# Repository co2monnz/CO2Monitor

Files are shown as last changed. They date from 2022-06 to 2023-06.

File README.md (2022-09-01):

# CO2 and Air Quality Monitor

**ESP32 DevKit (30pin) or Feather based**

Inspired by and many thanks to
[make-IoT / CO2-Ampel](https://github.com/make-IoT/CO2-Ampel) and [Umwelt-Campus](https://www.umwelt-campus.de/en/forschung/projekte/iot-werkstatt/translate-to-englisch-ideen-zur-corona-krise)

# Why use a CO2 Monitor?

A large risk of Covid-19 transmission stems from airborne virus particles that can linger in poorly ventilated spaces for hours. This has been recognised by the WHO. To lower the risk of infection, particularly in busier indoor settings, good ventilation and regular air exchange are key.

This is where measuring CO2 levels in rooms can provide a direct and good indication of sufficient ventilation which correlates with reduced viral load and low risk of virus transmission. Good air quality is also important for creating a good learning or work environment.

Poorly ventilated rooms often feel stale and ‘stuffy’, but by the time we can feel that the air quality is already pretty poor; early indications are easily missed. A sensitive and consistent CO2 monitor can accurately measure CO2 levels and display an easy-to-understand and actionable traffic light indication with orange as an indication of worsening air quality and red as a reminder to open a window.

The data collected by the sensors should be logged and made available for further consumption. It can be visualised on a central school/organisation-wide dashboard and used to establish a baseline and understand patterns or identify rooms that are more difficult to ventilate, as well as providing potential alerting or to remotely checking a room before another group uses it.

These CO2 monitors have been tested in collaboration with researchers from the public health department of the University of Otago.

## Resources

- [RNZ interview](https://www.rnz.co.nz/national/programmes/afternoons/audio/2018840570/handyman-dad-builds-units-to-monitor-class-air-quality)
- [The What, How and Why of CO2 Monitoring](https://makezine.com/2021/05/17/the-what-how-and-why-of-co-monitoring/)
- [Ventilation in NZ schools during the Omicron wave – results from a preliminary study](https://blogs.otago.ac.nz/pubhealthexpert/ventilation-in-nz-schools-during-the-omicron-wave-results-from-a-preliminary-study/)
- [Ministry of Education Indoor Air Quality and Thermal Comfort](https://assets.education.govt.nz/public/Documents/Primary-Secondary/Property/Design/Indoor-Air-Quality-and-Thermal-Comfort-V2-v2.0-2022.pdf)
- [What size particle is important to transmission of COVID-19?](https://www.aerosol.mech.ubc.ca/what-size-particle-is-important-to-transmission/)
- [Comparison of Low-Cost Particulate Matter Sensors for Indoor Air Monitoring during COVID-19 Lockdown](https://www.ncbi.nlm.nih.gov/pmc/articles/PMC7766947/pdf/sensors-20-07290.pdf)

# Sections

- [PCBs](#pcbs) listing the different PCB designs, [parts list](pcb/CO2%20Monitor%20V0.5%20through-hole/bom.md) and [assembly guide](pcb/CO2%20Monitor%20V0.5%20through-hole/step-by-step.md)
- [Firmware](#firmware) describing the device's software features and how to use them
- [Sensors](#sensors) has more information on the available sensors
- [Calibration](#calibration) has some important information on keeping the readings accurate
- [Hardware](#hardware) has a little more background on the controller and wiring

# PCBs

There are now 2 new PCB designs, one for SMD components and another one solely using easy to solder through-hole components.

## Through hole version

[BOM](pcb/CO2%20Monitor%20V0.5%20through-hole/bom.md)

[Assembly guide](pcb/CO2%20Monitor%20V0.5%20through-hole/step-by-step.md)

- uses only through hole components and can be hand soldered
- ESP 32 Devkit (30 pin)
- SCD30 NDIR CO2 sensor
- optional 128x64 0.96 inch OLED display
- 3 x 5mm red/yellow/green LEDs
- optional I2C JST-PH connector for additional connectivity (e.g. SPS30 particulate matter sensor)
- optional USB-B connector to power the monitor

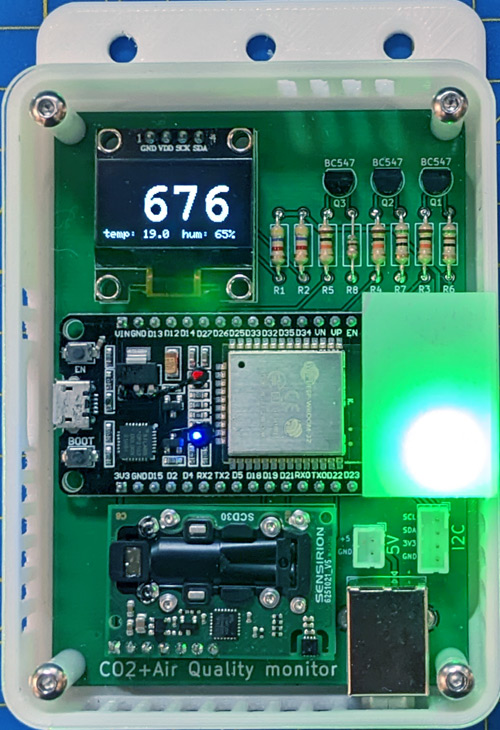
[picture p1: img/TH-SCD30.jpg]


## SMD version

- ESP 32 Devkit (30 pin)
- SCD40 or SCD30 NDIR CO2 sensor
- optional BME680 IAQ/VOC sensor
- optional 128x64 0.96 inch OLED display
- alternatively Feather wing footprint for easy expansion modules
- combined footprints for either 3 Neopixels (WS2812B 5050) or 3 x 5mm red/yellow/green LEDs
- I2C JST-PH connector for additional connectivity (e.g. SPS30 particulate matter sensor)
- optional USB-B connector to power the monitor

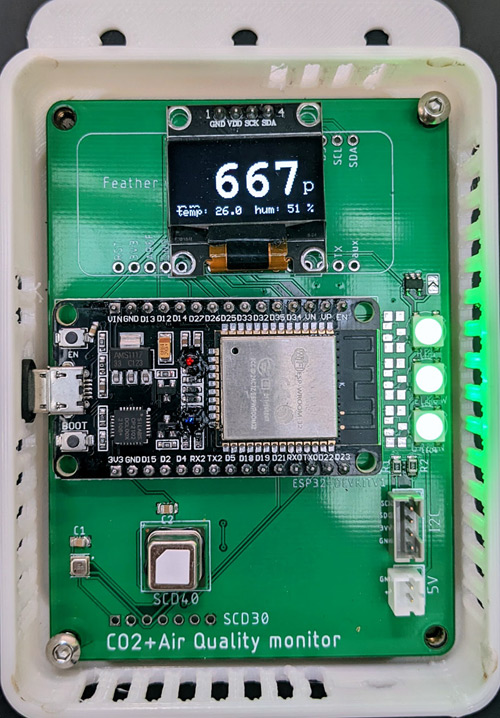
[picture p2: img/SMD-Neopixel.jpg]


## First generation

- ESP 32 Devkit (30 pin)
- SCD40 or SCD30 NDIR CO2 sensor
- optional BME680 IAQ/VOC sensor
- Feather wing footprint for easy expansion modules
- 3 x 5mm red/yellow/green LEDs
- I2C JST-PH connector for additional connectivity (e.g. SPS30 particulate matter sensor)
- RFM96 LoRa modem and u.Fl/SMA footprint

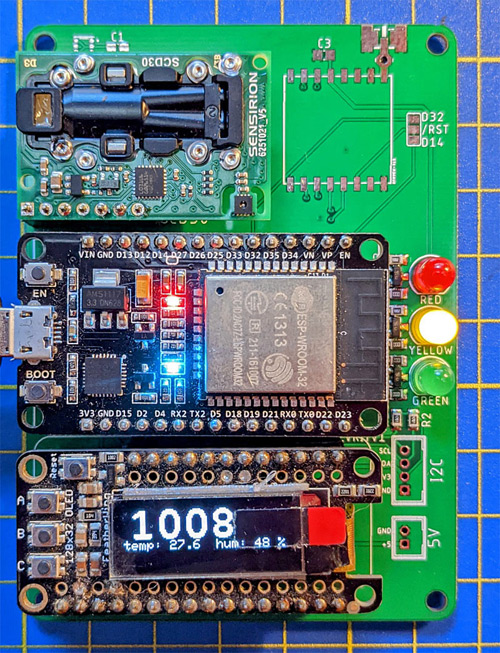
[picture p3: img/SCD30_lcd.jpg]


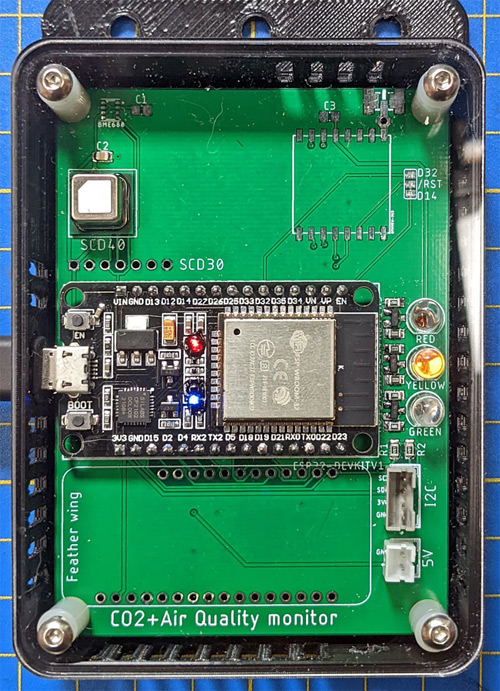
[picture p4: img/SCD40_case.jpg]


## First generation with Neopixel feather wing

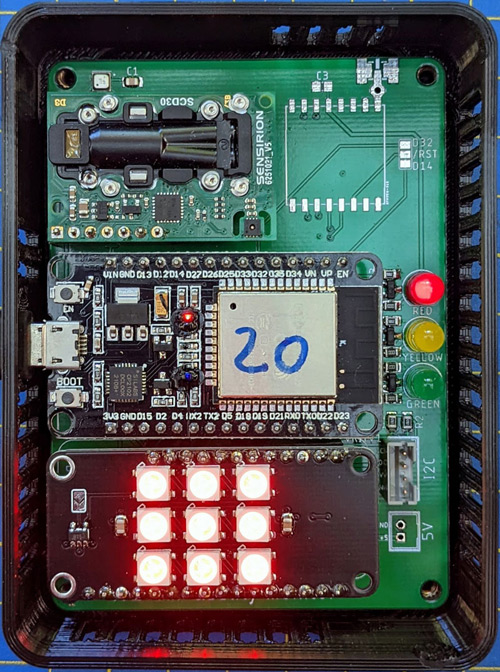
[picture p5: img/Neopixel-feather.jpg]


# Firmware




## Wifi

Supports [ESPAsync WiFiManager](https://github.com/khoih-prog/ESPAsync_WiFiManager) to set up wireless credentials and further configuration.

### Up to v1.2.3

If no wifi credentials have been configured yet it will automatically launch an AP using the SSID `CO2-Monitor-<ESP32mac>`.

Once wifi credentials have been configured briefly pressing the `Boot` button on the ESP32 puts the device in configuration mode:

### From v1.2.4

Pressing the `Boot` button for less than 2 seconds launches an AP using the SSID `CO2-Monitor-<ESP32mac>`. Connecting to this AP allows the Wifi credentials for the monitor to be set.

A password for the AP can be configured in the file `extra.ini` which needs to be created by copying [extra.template.ini](extra.template.ini) and applying the desired changes.



## Configuration

The monitor is configured via the `config.json` file on the ESP32 file system. There are 3 ways the configuration can be changed:

- via the web interface
- by directly editing [config.json](data/config.json) and uploading it via `Upload Filesystem Image`
- via MQTT (once connected)

## Backend using Mosquitto - Node-Red - InfluxDB - Grafana

[Docker compose file](./docker/docker.md) to set up the database and dashboards.

## MQTT

Sensor readings can be published via MQTT for centralised storage and visualition. Each node is configured with its own id and will then publish under `co2monitor/<id>/up/sensors`. The top level topic `co2monitor` is configurable. Downlink messages to nodes can be sent to each individual node using the id in the topic `co2monitor/<id>/down/<command>`, or to all nodes when omitting the id part `co2monitor/down/<command>`

SCD3x/SCD4x

```
{
  "co2": 752,
  "temperature": "21.6",
  "humidity": "52.1"
}
```

BME680

```
{
  "iaq": 19,
  "temperature": "19.2",
  "humidity": "75.6",
  "pressure": 1014
}
```

SPS30

```
{
  "pm0.5": 16,
  "pm1": 19,
  "pm2.5": 19,
  "pm4": 19,
  "pm10": 19
}
```

Sending `co2monitor/<id>/down/getConfig` will triger the node to reply with its current settings under `co2monitor/<id>/up/config`

```
{
  "appVersion": 1,
  "altitude": 10,
  "co2YellowThreshold": 700,
  "co2RedThreshold": 900,
  "co2DarkRedThreshold": 1200,
  "iaqYellowThreshold": 100,
  "iaqRedThreshold": 200,
  "iaqDarkRedThreshold": 300,
  "brightness": 255,
  "mac": "xxyyzz",
  "ip": "1.2.3.4",
  "scd40": true,
  "scd30": true,
  "bme680": true,
  "lcd": true,
  "sps30": true,
  "sps30AutoCleanInt": 604800,
  "sps30Status": 0,
  "tempOffset": "7.0",
  "ssd1306Rows": 64,
  "greenLed": 27,
  "yellowLed": 26,
  "redLed": 25,
  "neopixelData": 16,
  "neopixelNumber": 3,
  "featherMatrixData": 27,
  "featherMatrixClock": 13,
  "hub75R1": 15,
  "hub75G1": 2,
  "hub75B1": 4,
  "hub75R2": 16,
  "hub75G2": 12,
  "hub75B2": 17,
  "hub75ChA": 5,
  "hub75ChB": 18,
  "hub75ChC": 19,
  "hub75ChD": 14,
  "hub75Clk": 27,
  "hub75Lat": 26,
  "hub75Oe": 25
}
```

A message to `co2monitor/<id>/down/setConfig` will set the node's configuration to the provided parameters. Note that changes to the hardware configuration will trigger a reboot.

```
{
  "altitude": 10,
  "co2YellowThreshold": 700,
  "co2RedThreshold": 900,
  "co2DarkRedThreshold": 1200,
  "iaqYellowThreshold": 100,
  "iaqRedThreshold": 200,
  "iaqDarkRedThreshold": 300,
  "brightness": 255,
  "ssd1306Rows": 64,
  "greenLed": 27,
  "yellowLed": 26,
  "redLed": 25,
  "neopixelData": 16,
  "neopixelNumber": 3,
  "featherMatrixData": 27,
  "featherMatrixClock": 13,
  "hub75R1": 15,
  "hub75G1": 2,
  "hub75B1": 4,
  "hub75R2": 16,
  "hub75G2": 12,
  "hub75B2": 17,
  "hub75ChA": 5,
  "hub75ChB": 18,
  "hub75ChC": 19,
  "hub75ChD": 14,
  "hub75Clk": 27,
  "hub75Lat": 26,
  "hub75Oe": 25
}
```

A message to `co2monitor/<id>/down/setTemperatureOffset` will set the SCD3x/SCD4x's temperature offset (float, °C):

```
7.0
```

A message to `co2monitor/<id>/down/calibrate` will manually calibrate the SCD3x/SCD4x sensor to the given value:

```
412
```

A message to `co2monitor/<id>/down/setSPS30AutoCleanInterval` will set the SPS30 fan auto-clean interval in seconds to the given value:

```
604800
```

A message to `co2monitor/<id>/down/cleanSPS30` will run a fan clean on the SPS30.

A message to `co2monitor/<id>/down/reboot` will trigger a reset on the node.

### MQTT TLS support

To connect to an MQTT server using TLS (recommended) you need to enable TLS in the configuration by setting `mqttUseTls` to `true`. You also need to supply a root CA certificate in PEM format on the file system as `/mqtt_root_ca.pem` and/or a client certificate and key for using mTLS as `mqtt_client_cert.pem` and `mqtt_client_key.pem`. These files can be uploaded using the `Upload Filesystem Image` project task in PlatformIO. Alternatively you can set `mqttInsecure` to `true` to disable certificate validation altogether.

## Supported sensors

- [SCD3x NDIR CO2, temperature and humidity sensor](https://www.sensirion.com/en/environmental-sensors/carbon-dioxide-sensors/carbon-dioxide-sensors-scd30/)
- [SCD4x NDIR CO2, temperature and humidity sensor](https://www.sensirion.com/en/environmental-sensors/carbon-dioxide-sensors/carbon-dioxide-sensor-scd4x/)
- [BME680 IAQ, VOC, temperature and humidity sensor](https://www.bosch-sensortec.com/products/environmental-sensors/gas-sensors/bme680/)
- [SPS30 Small Particulate matter sensor](https://sensirion.com/products/catalog/SPS30/)

## Supported displays

- [128x32 OLED feather wing](https://www.adafruit.com/product/2900)
- [SSD1306 based displays](https://www.aliexpress.com/wholesale?SearchText=128X64+SSD1306)
- [Dot Star feather wing](https://www.adafruit.com/product/3449)
- [Neopixel feather wing](https://www.adafruit.com/product/2945)
- Neopixel strips
- [HUB75 based RBG Matrix panels](https://www.adafruit.com/?q=RGB+LED+Matrix+Panel&sort=BestMatch)

# Sensors

The presence of supported I2C based sensors/displays will be automatically detected on start-up.

## SCD3x

A SCD3x NDIR CO2 sensor can be connected to the designated footprint and will provide CO2, temperature and humidity readings via I2C. It supports a separate ready signal which is connected to the ESP32.

## SCD4x

A SCD4x NDIR CO2 sensor can be soldered directly onto the pcb and provides CO2, temperature and humidity readings via I2C.

## BME680

A BME680 sensor can be directly soldered onto the dedicates footprint or connected via the I2C JST header [Adafruit BME680](https://www.adafruit.com/product/3660), [STEMMA to JST SH Cable](https://www.adafruit.com/product/4424) to provide additional VOC and AIQ measurements.

## SPS30 Particulate matter sensor

The SPS30 sensor can be connected to the I2C and 5V JST connectors of the pcb.

| fn  | I2C | 5V  | SPS30 |
| --- | --- | --- | ----- |
| VDD | | +5V | 1 |
| SDA | SDA | | 2 |
| SCL | SCL | | 3 |
| SEL | GND | | 4 |
| GND | | GND | 5 |

## other

Other I2C based sensors can be wired using the JST-PH I2C header.

# Calibration

CO2 sensors need to be regularly calibrated to provide reliable measurements. The used sensors support auto-calibration and that is enabled in the firmware. It works by looking over measurements over a period and calibrating the lowest value against 420ppm (configurable in the firmware). This is based on the assumption that the monitor 'sees' clean outside air about once a week. If that cannot be achieved the firmware also allows for a forced calibration against a given value. Please also make sure to set the altitude setting according to the monitor location. For details please check the sensor's datasheets.

## From v1.2.4

Manual calibration can be triggered by pressing the `Boot` button for more than 5 seconds. Make sure the monitor has been exposed to fresh outside air for a while and be careful not to breathe towards the monitor when doing this.

# Hardware

The board was designed to use an ESP32 or a Feather controller

## ESP32

When an ESP32 is used the feather footprint can be used to drive feather wings. Since some pins are shared with other components please check carefully before connecting a feather.

## Feather

A feather controller can be used to drive the sensors and LEDs, but unfortunately not the RFM96.

## Pin mapping

| ESP32 Devkit (30 pin) | fn | Feather pin | fn | LEDs | SCD3x/4x/BME680/SPS30 | Neopixel |
| --- | --- | --- | ----- | --- | --- | --- |
| 1 | EN | | | | | |
| 2 | VP-D36 | 9 | A4 | | | |
| 3 | VN-D39 | 8 | A3 | | | |
| 4 | D34 | 7 | A2 | | | |
| 5 | D35 | | | | RDY (SCD3x) | |
| 6 | D32 | 20 | D6 | | | |
| 7 | D33 | 22 | D10 | | | |
| 8 | D25 | 6 | A1 | Red | | |
| 9 | D26 | 5 | A0 | Yellow | | |
| 10 | D27 | 23 | D11 | Green  | | |
| 11 | D14 | 19 | D5 | | | |
| 12 | D12 | 24 | D12 | | | |
| 13 | D13 | 25 | D13 | | | |
| 14 | GND | | | | | |
| 15 | V_in | 26 | V_USB | | | |
| 16 | 3V3 | 2 | 3V3 | | | |
| 17 | GND | 4 | GND | | | |
| 18 | D15 | 21 | D9 | | | |
| 19 | D2 | | | | | |
| 20 | D4 | 10 | A5 | | | |
| 21 | D16 | | | | | DIN |
| 22 | D17 | | | | | |
| 23 | D5/CS0 | | | | | |
| 24 | D18/SCK  | 11 | SCK | | | |
| 25 | D19/MISO | 13 | MISO  | | | |
| 26 | D21/SDA  | 17 | SDA | | SDA | |
| 27 | D3/Rx | 14 | Rx | | | |
| 28 | D1/TxD | 15 | Tx | | | |
| 29 | D22/SCL  | 18 | SCL | | SCL | |
| 30 | D23/MOSI | 12 | MOSI  | | | |
| | | 1 | RST | | |
| | | 3 | AREF  | | |
| | | 16 | aux | | |
| | | 27 | En | | |
| | | 28 | VBat  | | |

## LEDs

The board has room for 3 x 5mm LEDs for traffic light style indication. Each is driven by a transistor to relieve the ESP32/Feather GPIO pins. High intensity LEDs allow for good visibility, but can also be dimmed using the ESP32 internal PWM channels if needed.

- [Green, 12.5cd, 30°, 20 mA, 3.2 V](https://nz.element14.com/cree/lc503fpg1-30q-a3-00001/led-5mm-green/dp/1648988) (use 5Ω resistor)
- [Yellow, 9.3cd, 30°, 20 mA, 2.1 V](https://nz.element14.com/broadcom-limited/hlmp-el3g-vx0dd/led-amber-9-3cd-590nm-th/dp/2900814) (use 60Ω resistor)
- [Red, 9.3cd, 30°, 20 mA, 2.1 V](https://nz.element14.com/broadcom-limited/hlmp-eg3a-wx0dd/led-5mm-alingap-red-30deg/dp/1706677) (use 60Ω resistor)

Set the `greenLed`, `yellowLed` and `redLed` configuration properties to valid pin numbers (`27`, `26`, `25`).

## Neopixel

Set the `neopixelData` and `neopixelNumber` configuration properties to the neopixel pin number (`16`) and the number of neopixels (`3`).

## Feather wings

### [6 x 12 DotStar](https://www.adafruit.com/product/3449)

Set the `featherMatrixData` and `featherMatrixClock` configuration properties to the feathermatrix data (`27`) and clk (`13`) pin numbers.

### [128x32 OLED](https://www.adafruit.com/product/2900)

Set the `ssd1306Rows` configuration to `32`

### [128x64 OLED](https://www.aliexpress.com/wholesale?SearchText=128X64+SSD1306)

Set the `ssd1306Rows` configuration to `64` (default setting)

### [64x32 RBG Matrix panel](https://www.adafruit.com/?q=64x32+RGB+LED+Matrix&sort=BestMatch)

Set the `hub75*` configuration properties to the correct pin numbers.

## RFM96 (first generation)

This allows adding a LoRa modem when no WiFi is available to transmit measurements.

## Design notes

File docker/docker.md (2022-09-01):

# Docker backend running Mosquitto InfluxDB Node-Red Grafana

## Preparation

Before running the docker compose file have a look at the various \*.env files and change the provided default passwords.
Make sure not to expose this directly to the internet without additional and read the following resources on further securing the various components

- [Grafana](https://grafana.com/docs/grafana/next/setup-grafana/configure-security/)
- [Node-Red](https://nodered.org/docs/user-guide/runtime/securing-node-red)
- [Mosquitto](https://mosquitto.org/documentation/)
- [InfluxDB](https://hub.docker.com/_/influxdb)
- Set a `credentialSecret` in [Node Red's settings.js](./nodered/settings.js#L44)

## Starting

Run `docker-compose up`

## Mosquitto

- Mosquitto is pre-configured using the [mosquitto.acl](./mosquitto/config/mosquitto.acl) and [mosquitto.passwd](./mosquitto/config/mosquitto.passwd) files. The default users/passwords are
  - `admin` // `admin`
  - `co2monitor` // `co2monitor`
  - `nodered` // `nodered`
- to change any of the above passwords use `docker exec mosquitto mosquitto_passwd -b /mosquitto/config/mosquitto.passwd {username} {password}`. Restart Mosquitto for the changes to become effective `docker restart mosquitto`

## Configure InfluxDB

### Using the UI

- Open http://127.0.0.1:8086/ and log on using the admin user and password form the [influxdb.env](influxdb.env) file
- Navigate to `Load data` -> `API tokens` and generate a `Read/Write API Token` for Node-red
  - Description `nodered`
  - Select scoped read and write access for the `co2monitors` bucket
  - the token will later be entered in a Node-red configuration node
- Create another token for Grafana
  - Description `grafana`
  - Select scoped read access for the `co2monitors` bucket
  - the token will later be entered in Grafana

### Using the CLI

- Create and note API tokens
  - Node-red `docker exec influxdb bash -c "influx auth create -o CO2Monitors -d nodered --write-bucket $(influx bucket list | grep co2monitors | cut -f 1) --read-bucket $(influx bucket list | grep co2monitors | cut -f 1) | grep nodered | cut -f 4"`
  - Grafana `docker exec influxdb bash -c "influx auth create -o CO2Monitors -d grafana --read-bucket $(influx bucket list | grep co2monitors | cut -f 1) | grep grafana | cut -f 4"`
- (optional) run `docker exec influxdb bash -c "influx auth list --user admin --hide-headers | cut -f 3"` to retrieve the admin API token

## Configure Node-Red

### Using the UI

- Open http://127.0.0.1:1880/
- Open the `Manage palette` menu to add the missing plug-ins
- Got to the `Install` tab and add the following plug-ins
  - node-red-contrib-influxdb
  - node-red-dashboard
  - node-red-node-email
- Open `Configuration nodes` in the menu and select open the `[v2.0] influxdb` node
- Enter the `nodered` API token previously created in InfluxDB
- Open the `Mosquitto` Docker configuration node and enter the Mosquitto username and password (default `nodered` // `nodered` )
- Deploy the changes using the top right Deploy menu. Deploying `Modified nodes` only is sufficient. The Mosquitto nodes should now show `connected`
- to enable email alerts and status messages configure the email node and enable it.

### Using the CLI

- Install the missing plug-ins `docker exec nodered npm install node-red-contrib-influxdb node-red-dashboard node-red-node-email`
- Restart Node-Red `docker restart nodered`
- Follow the steps above to configure the `Configuration nodes` on hte UI

### Finishing

- Once you have a CO2 monitor connected check out the Node-Red Dashboard http://127.0.0.1:1880/ui/. You might need to trigger the `Refresh monitors` flow in the `CO2 Monitors UI` tab first, or wait until it runs every hour.
- The `Get configuration` flow on the `CO2 monitors` tab runs daily and queries all monitors for their current configuration. This will show on the UI once a monitor is selected in the drop down and is also visible in the dedicated Grafana dashboard.

## Configure Grafana

- Open http://127.0.0.1:3000/ and log in using the user and password configured in [`grafana.env`](grafana.env)
- Open the `Data sources` entry from the bottom left Configuration menu and click on `InfluxDB`
- Enter the grafana token previously created in Influx
- Confirm with `Save and test`

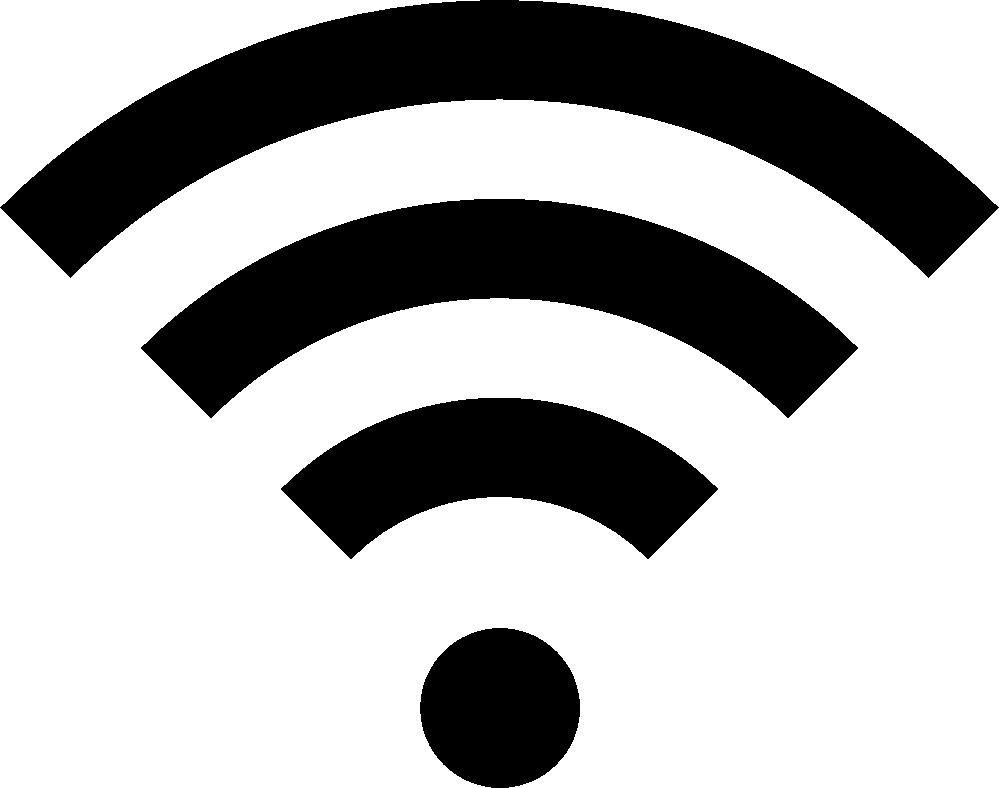
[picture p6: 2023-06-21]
esphome/img/wifi.png

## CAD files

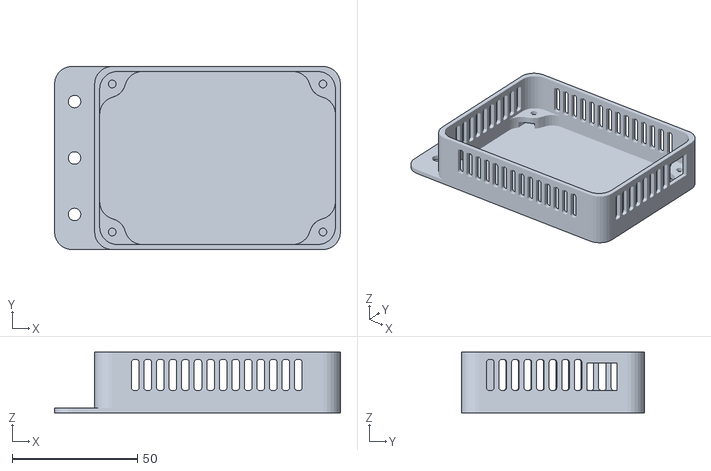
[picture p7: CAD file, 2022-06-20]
case/Case v0.5_15mm_USB.STL
114.0 x 73.0 x 24.3

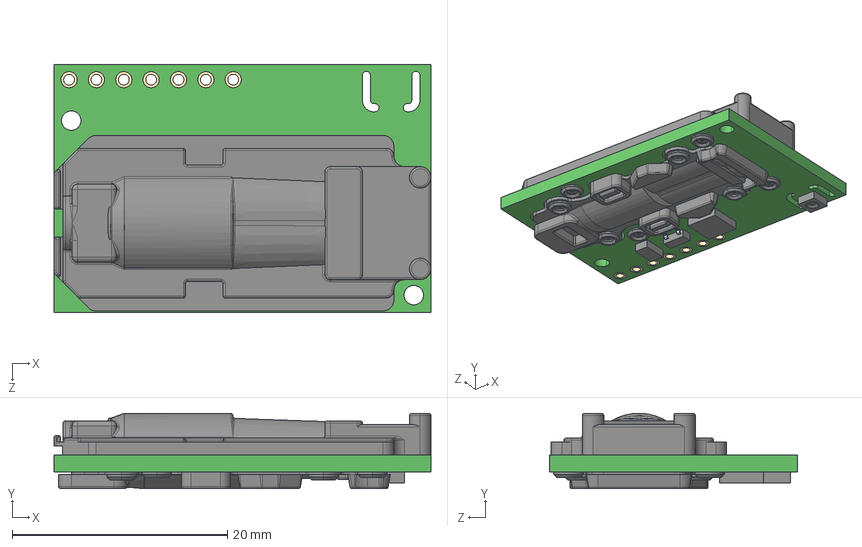
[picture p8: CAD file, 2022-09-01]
pcb/CO2 Monitor V0.5 SMD/3dmodels/SCD30--3DModel-STEP-56544.STEP
35.0 x 7.00 x 23.0 mm

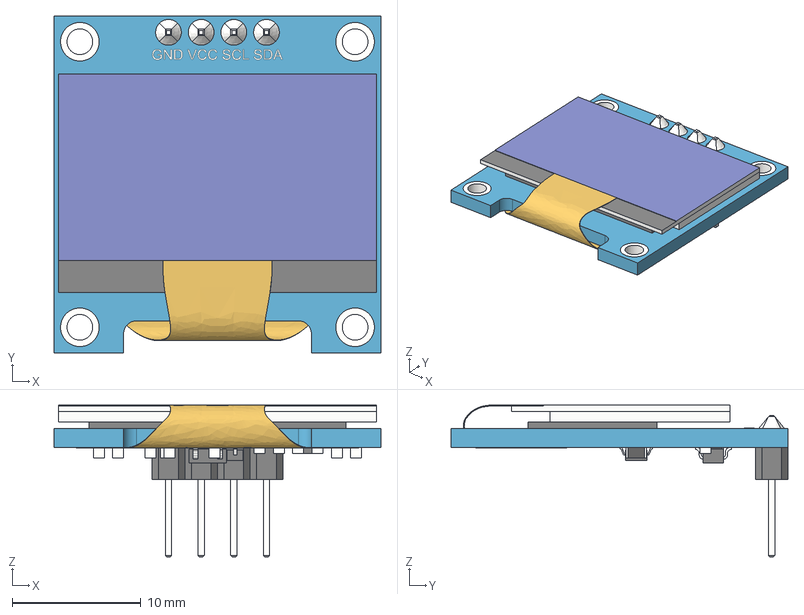
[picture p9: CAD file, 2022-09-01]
pcb/CO2 Monitor V0.5 through-hole/3dmodels/SSD1306_OLED_Display(128x64).step
25.4 x 26.2 x 11.8 mm
board
screen
pin_header
soldering
smd_capacitor
smd_capacitor (1)
914_smd_resistor
472_smd_resistor x 3
t4_smd_diode
smd_capacitor (2)
smd_capacitor (3)
smd_capacitor (4)
smd_capacitor (5)
smd_capacitor (6)
472_smd_resistor (1)
SOT-23_XC6206 v3
smd_capacitor (7)
flat_cable

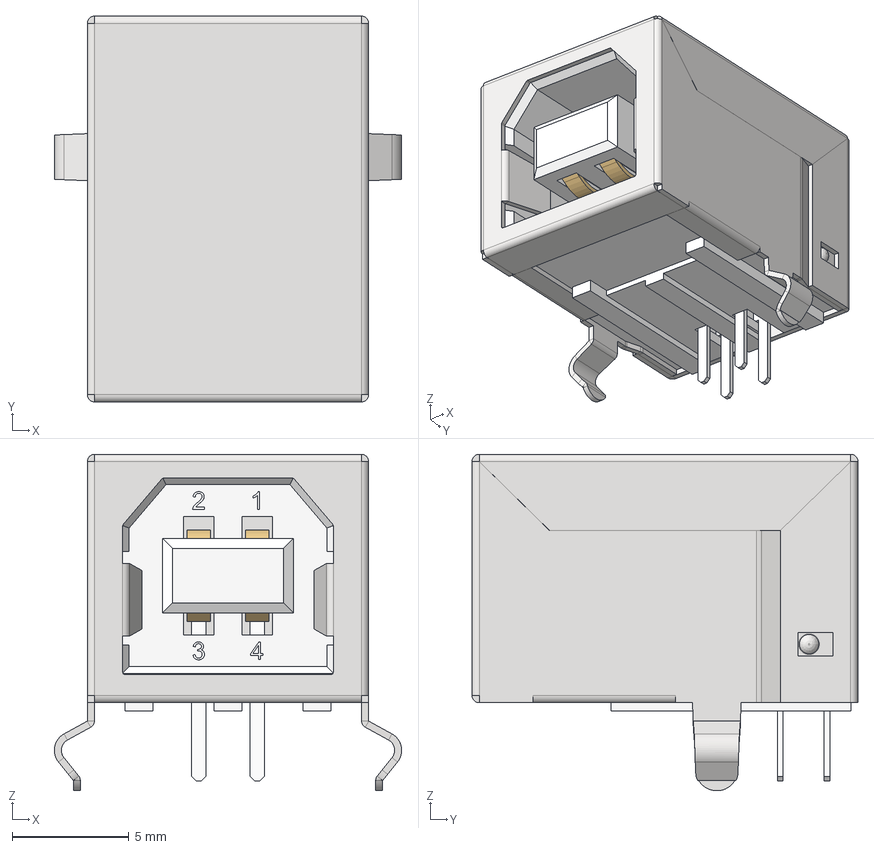
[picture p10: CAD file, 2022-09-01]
pcb/CO2 Monitor V0.5 through-hole/3dmodels/USB 2.0 Type B Connector Right Angle (Würth 61400416121).stp
14.8 x 16.5 x 14.4 mm

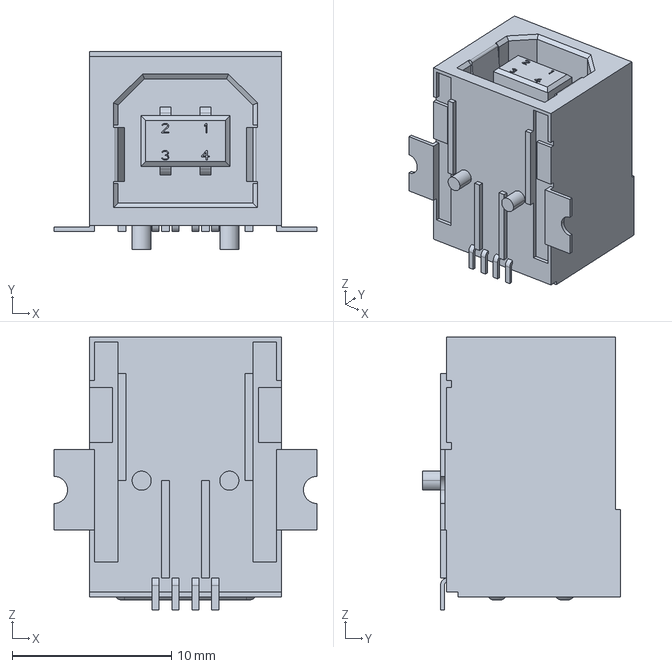
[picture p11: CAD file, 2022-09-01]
pcb/CO2 Monitor V0.5 SMD/3dmodels/USB-B-SMD 1-1734346-1.step
16.5 x 12.4 x 17.1 mm

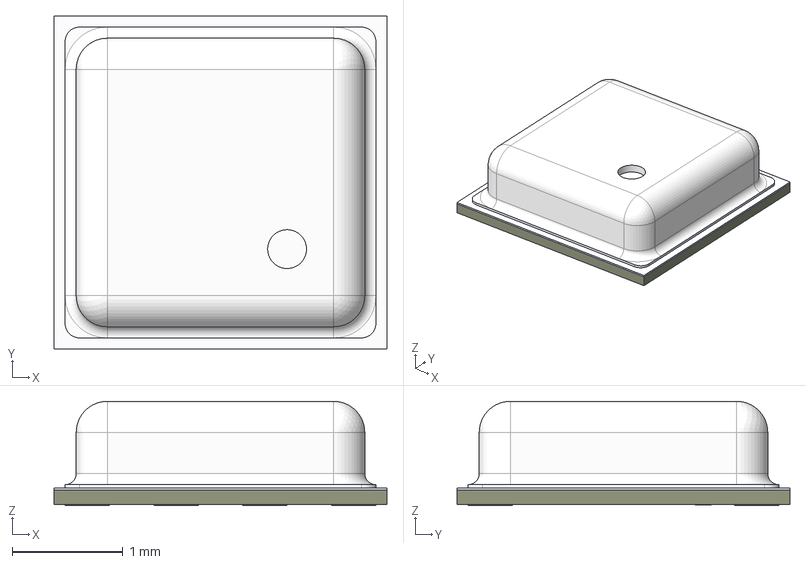
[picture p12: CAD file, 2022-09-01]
pcb/CO2 Monitor V0.5 SMD/3dmodels/BME680.step
3.00 x 3.00 x 0.94 mm
pads
pcb
lid

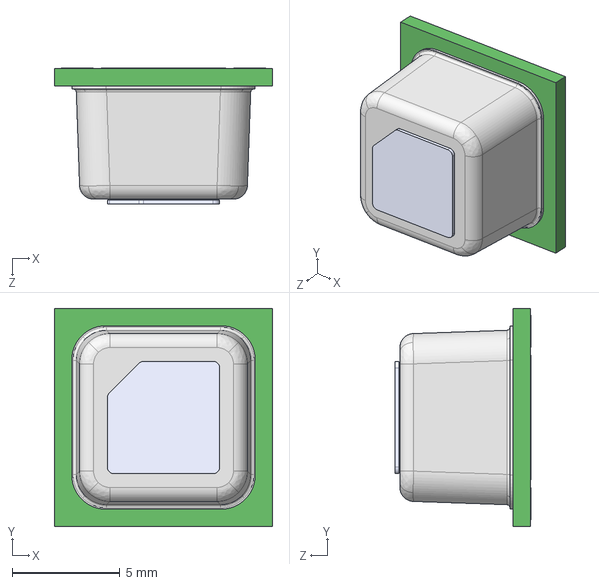
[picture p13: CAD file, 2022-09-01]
pcb/CO2 Monitor V0.5 SMD/3dmodels/SCD40-D-R2--3DModel-STEP-369182.STEP
10.1 x 10.1 x 6.31 mm

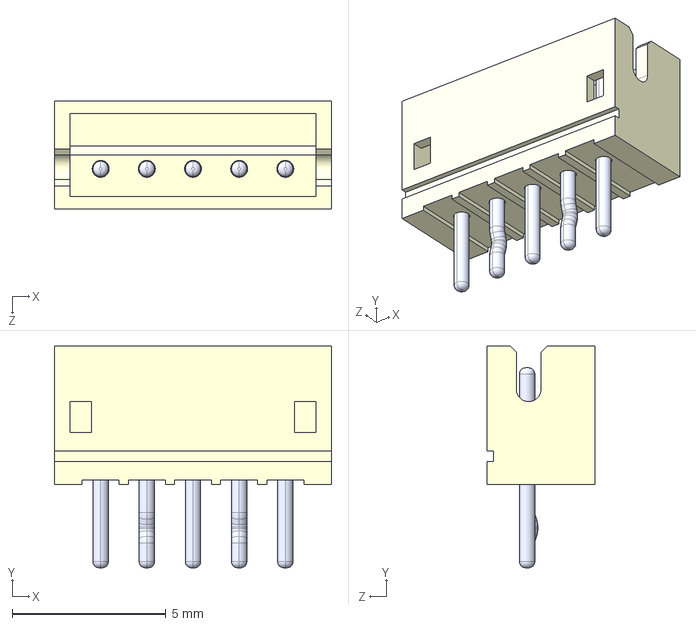
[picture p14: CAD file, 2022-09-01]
pcb/CO2 Monitor V0.5 SMD/3dmodels/B5B-ZR_LF__SN_.step
9.00 x 7.20 x 3.50 mm

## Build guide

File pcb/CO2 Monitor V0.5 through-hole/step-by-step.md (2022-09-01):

# CO2 monitor through-hole step by step assembly guide

This guide will take you through all necessary steps to assemble the through-hole version of the CO2 monitor if you ware building your own from a kit or parts that you have sourced yourself.

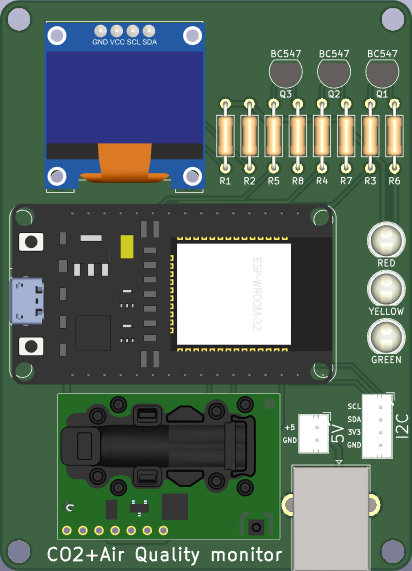
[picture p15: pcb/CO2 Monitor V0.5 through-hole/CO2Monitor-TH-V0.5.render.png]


## Preparations

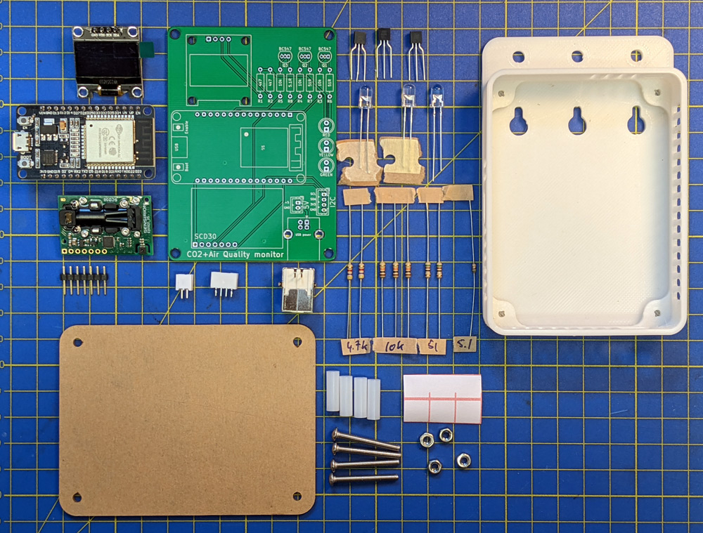
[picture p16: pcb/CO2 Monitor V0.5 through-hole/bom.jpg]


Before you start make sure you have all [required parts](./bom.md) and tools ready. You'll need:

- soldering iron
- solder
- good ventilation and ideally a solder fume extractor
- side cutters
- safety glasses
- USB power
- micro USB cable
- 2mm hex (Allen) key
- (optional) multimeter

## PCB assembly

1. Start with soldering the resistors to the PCB. If you are unsure about the resistor values and don't have a multimeter handy use a [resistor colour code decoder](https://www.digikey.co.nz/en/resources/conversion-calculators/conversion-calculator-resistor-color-code) to confirm the correct value. Bend the resistors at ~10mm and put them through the PCB before soldering them in place. Cut the wires close to the PCB once soldered in place.

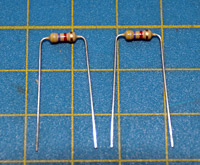
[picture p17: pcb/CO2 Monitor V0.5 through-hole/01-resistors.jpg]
   

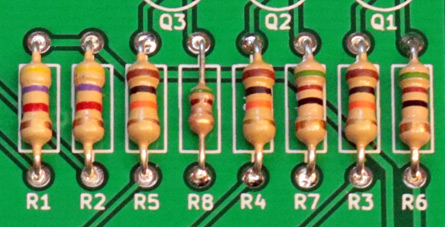
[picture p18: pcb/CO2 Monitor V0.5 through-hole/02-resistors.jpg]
   

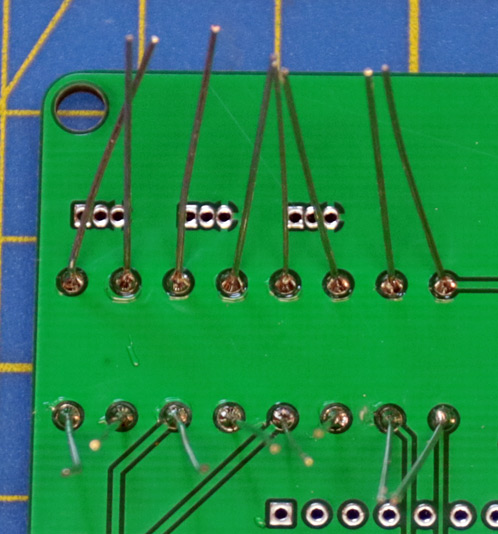
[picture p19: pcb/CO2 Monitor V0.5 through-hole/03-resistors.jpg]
   

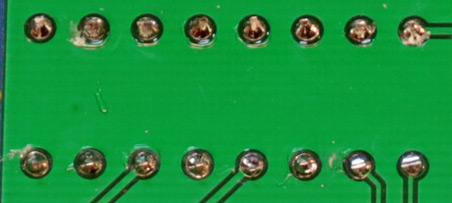
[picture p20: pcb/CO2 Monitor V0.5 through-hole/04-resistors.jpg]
   

2. Place the 3 BC547 transistors in place making sure the flat side of the package aligns with the shape of the silkscreen. You might have to bend the wires a little to make them fit. You don't need to push them all the way to the bottom, but make sure that the wires don't touch each other.

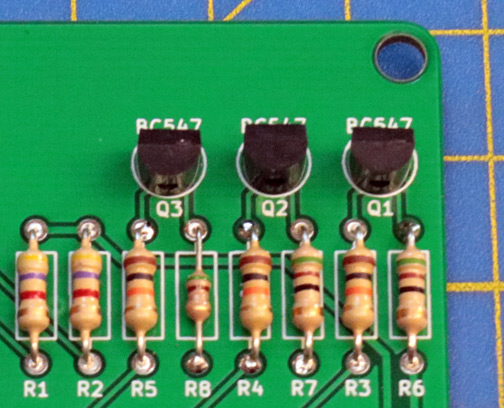
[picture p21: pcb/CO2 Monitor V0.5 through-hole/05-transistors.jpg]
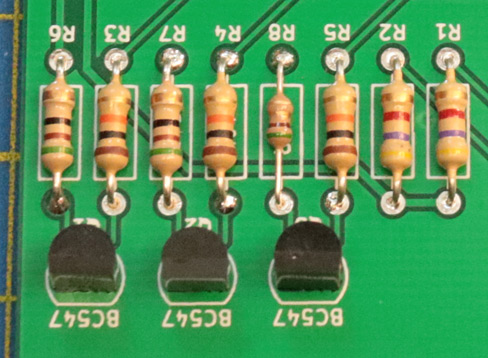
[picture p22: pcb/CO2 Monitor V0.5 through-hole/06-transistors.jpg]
    

3. The 3 LEDs must be installed in the correct orientation with the anode (+ side) facing the top of the PCB. The lead on the anode is a little longer. You can also check the correct orientation with a multimeter

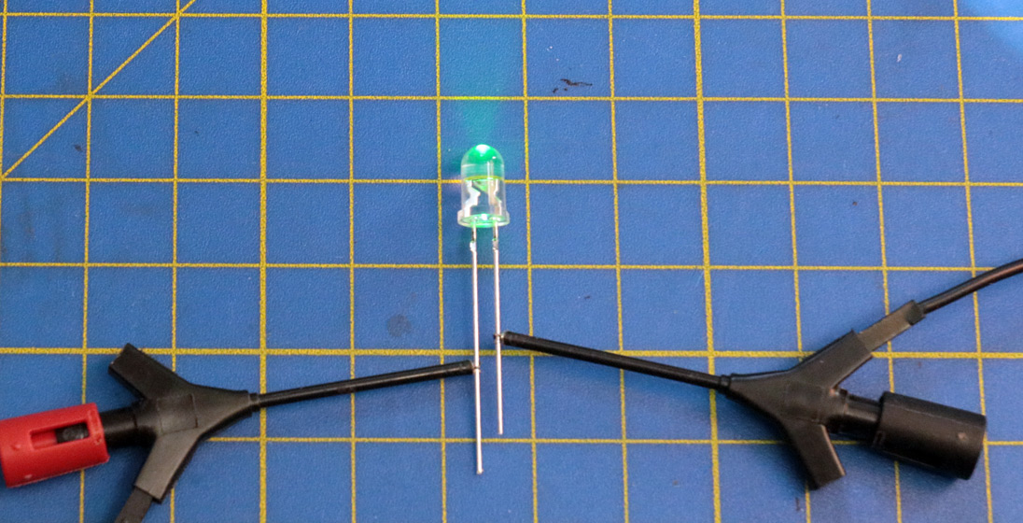
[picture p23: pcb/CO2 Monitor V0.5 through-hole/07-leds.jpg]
   

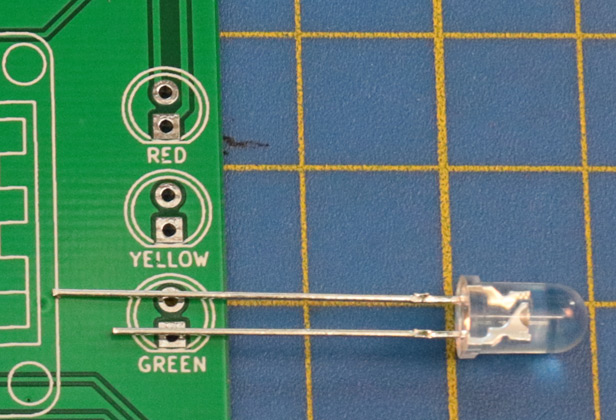
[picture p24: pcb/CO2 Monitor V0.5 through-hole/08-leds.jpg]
   

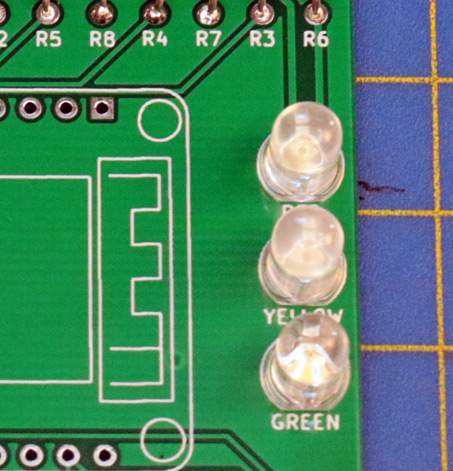
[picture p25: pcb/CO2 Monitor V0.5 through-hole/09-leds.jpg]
   

4. The ESP32 micro controller comes next. Make sure to install it in the right direction with the USB port facing left. It can be a little difficult to push in if the pins don't perfectly align. In that case start at one side and slowly move from pin to pin, carefully pushing each pin into position. Start soldering at one end and check that it is fully inserted after soldering the first pin before continuing with the reamining pins. When you're done soldering the pins will need to be shortened with a wire cutter for the PCB to properly fit into the case. When clipping the pins be careful since they are thicker than resistor wires and tend to fly away. Wear safety glasses and cover then pins with a cloth/rug when clipping them.

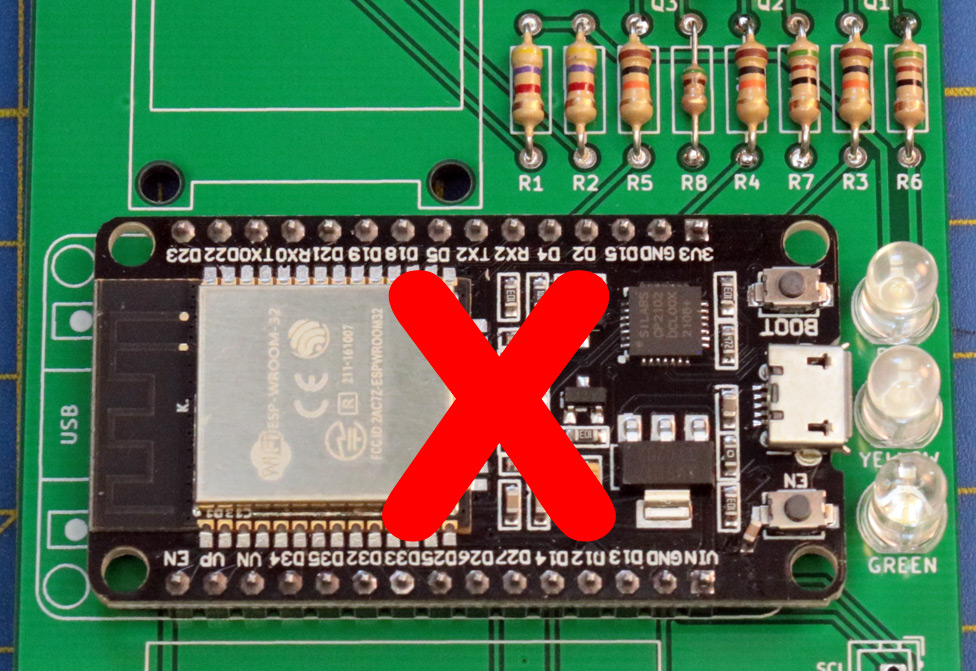
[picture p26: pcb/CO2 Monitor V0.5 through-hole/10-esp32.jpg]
   

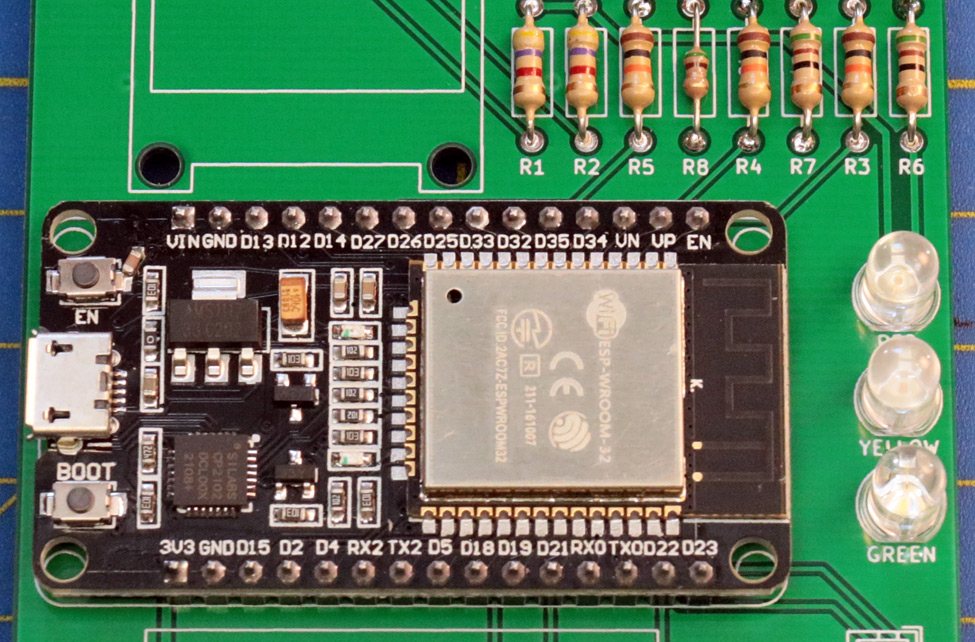
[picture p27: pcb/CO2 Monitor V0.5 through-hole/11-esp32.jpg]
   

5. Solder only one pin of the display before checking the correct alignment. It's easier to adjust while only one pin is connected. Then solder the remaining pins. Leave the protective film on the display for now.

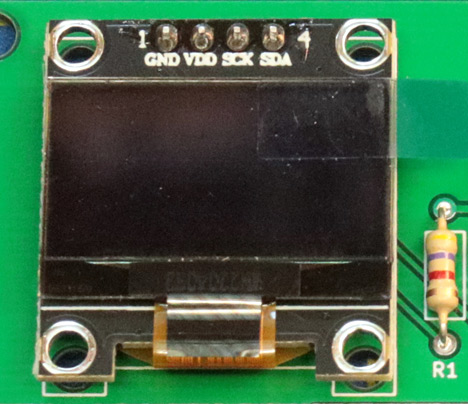
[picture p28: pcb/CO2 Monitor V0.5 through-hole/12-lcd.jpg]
   

6. If the SCD30 sensor comes without a pre-soldered pin header, solder a 7 pin header to the sensor first. If you have a prototyping bread board available use it to keep the pin header straight; otherwise carefully solder one pin only and adjust as needed before completing the remaining ones.

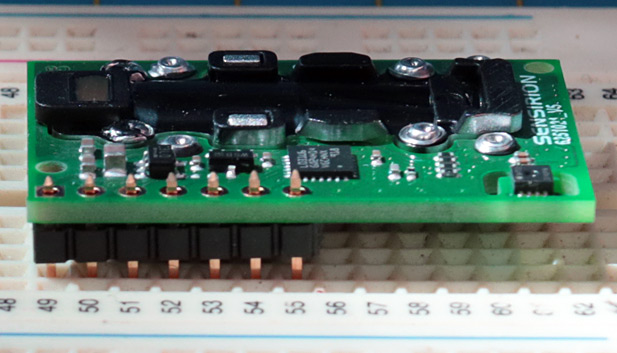
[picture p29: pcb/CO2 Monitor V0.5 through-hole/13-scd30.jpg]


Solder the SCD30 sensor to the main PCB while making sure it lies flat on the board. Don't push the pins in all the way.

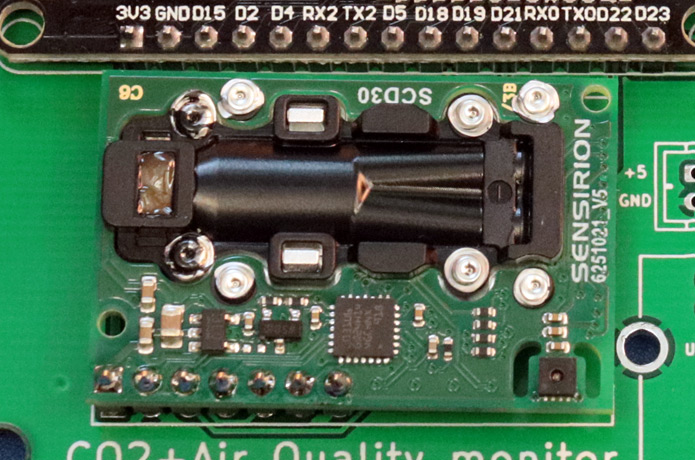
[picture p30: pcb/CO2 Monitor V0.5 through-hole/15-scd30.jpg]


7. (optional) Place and solder the JST headers for power and I2C and the USB-B power connector.

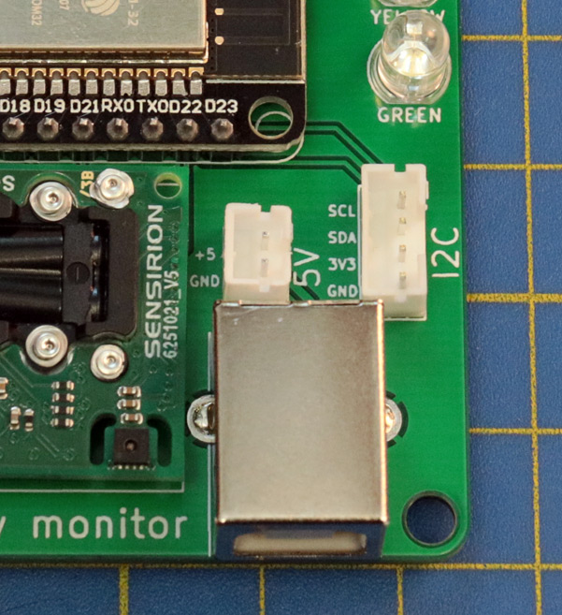
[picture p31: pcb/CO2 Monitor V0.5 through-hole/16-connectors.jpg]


8. (optional) Apply a small amount of liquid electrical tape over the 2 LEDs on the ESP32 to reduce their brightness.

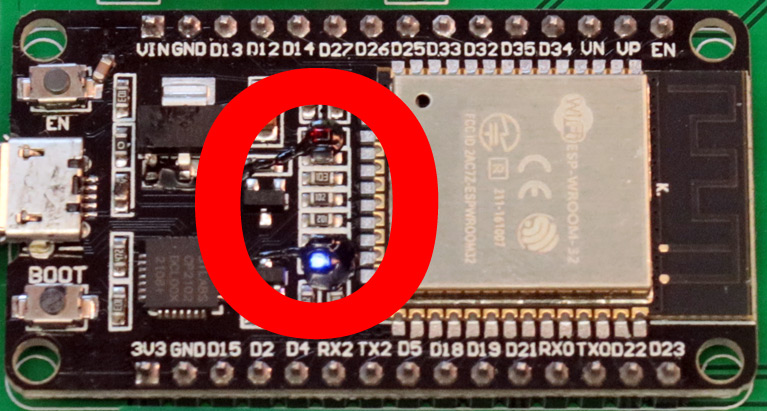
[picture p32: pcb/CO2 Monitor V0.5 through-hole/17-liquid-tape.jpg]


9. Before plugging the monitor in, have a good look at all components and make sure that all components are installed in the correct location and orientation, all solder joints are well done and not short circuited and everything looks right. Then plug a micro-USB cable into the ESP32 and flash the firmware.
   The monitor will start up and display the name of its WiFi access point in the first row on the display. After a short while it will also show a CO2 reading. Don't worry that the LEDs don't turn on quite yet as they'll need to be enabled in the configuration first.

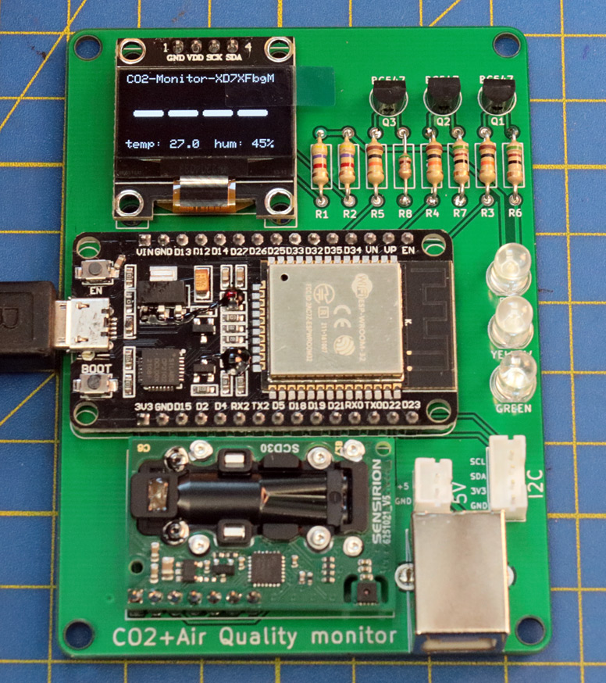
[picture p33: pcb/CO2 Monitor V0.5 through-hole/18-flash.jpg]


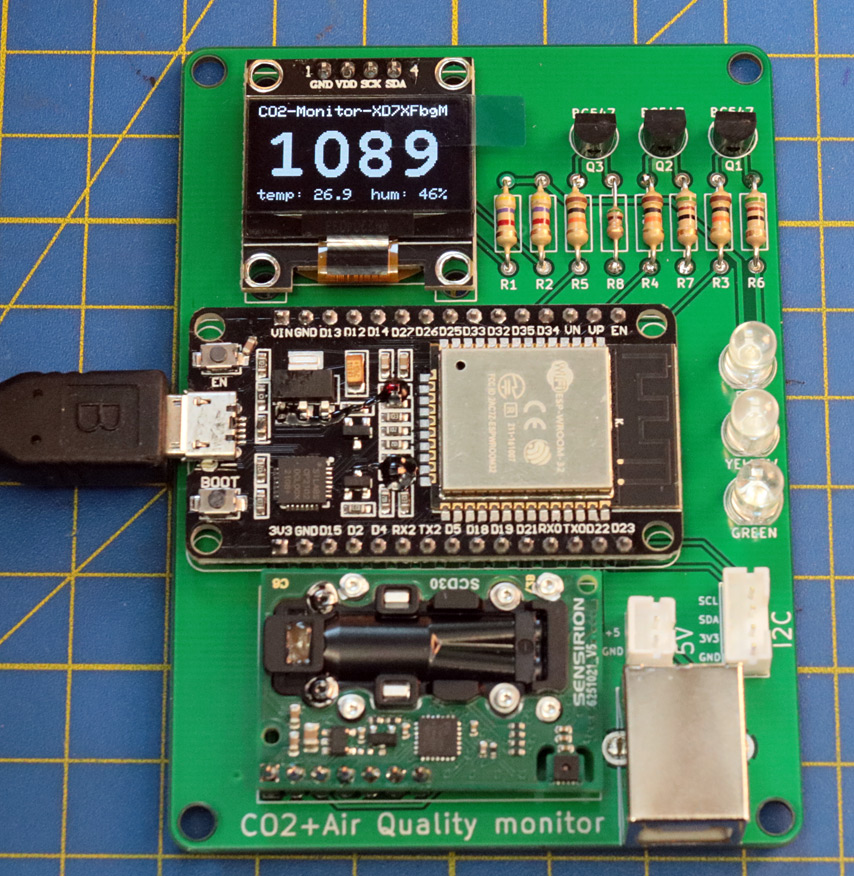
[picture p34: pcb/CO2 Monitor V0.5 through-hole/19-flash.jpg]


10. Connect to the monitor's Wifi access point and configure the Wifi and enable the LEDs by setting the following in the configuration:

```
  "greenLed": 27,
  "yellowLed": 26,
  "redLed": 25,
```

You'll then see the LEDs light up according to the CO2 reading. The electrical part of the assembly is complete.

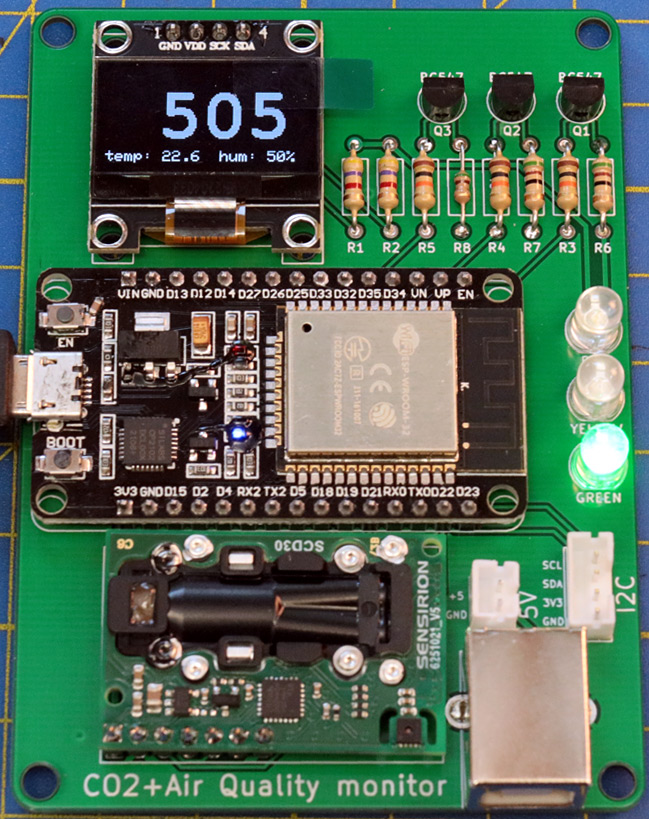
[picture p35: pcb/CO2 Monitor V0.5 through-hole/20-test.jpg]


11. There are 2 ways to install the monitor in the case. Placing it upside down on the front panel can be easier.
    Remove the protective film from the acrylic front panel and the LCD. Push the 4 screws through the front panel and place it on a flat surface with the screw heads facing down. Then push the stand offs over the screws before placing the PCB upside down over the screws.

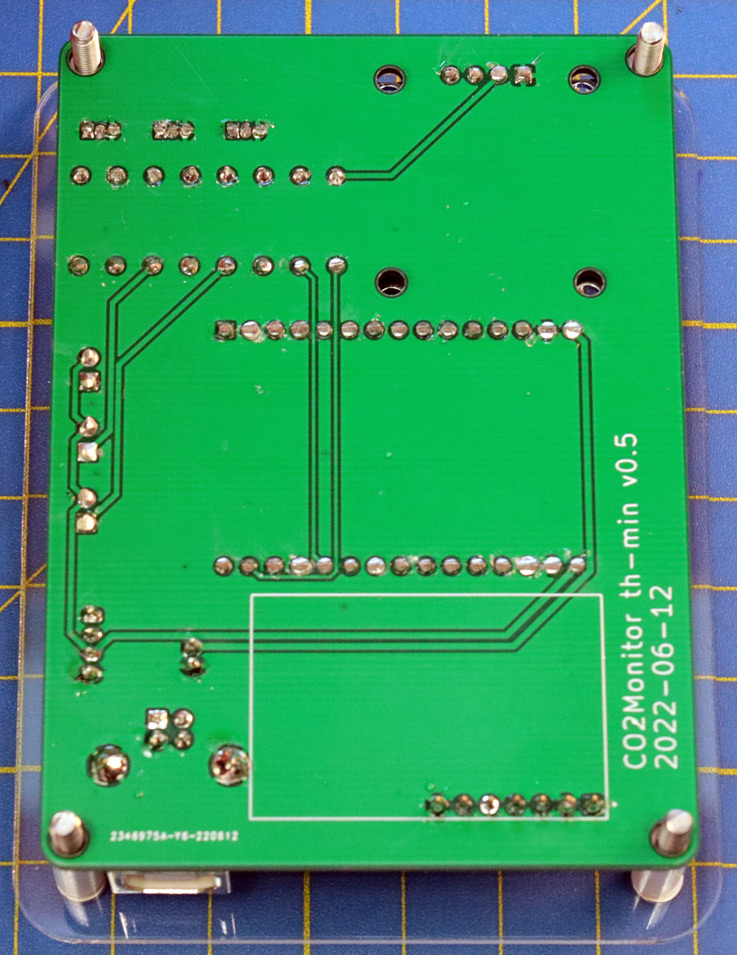
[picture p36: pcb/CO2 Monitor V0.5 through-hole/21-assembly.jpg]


Then place the case upside down over the screws, carefully pushing the screws through the holes. Place the hex nuts, carefully lift the case sideways and secure the screws with a hex (Allen) key without overtightening them. You can use a little bit of glue, electrical tape or similar to hold the hex nuts in place and stop them from falling out.

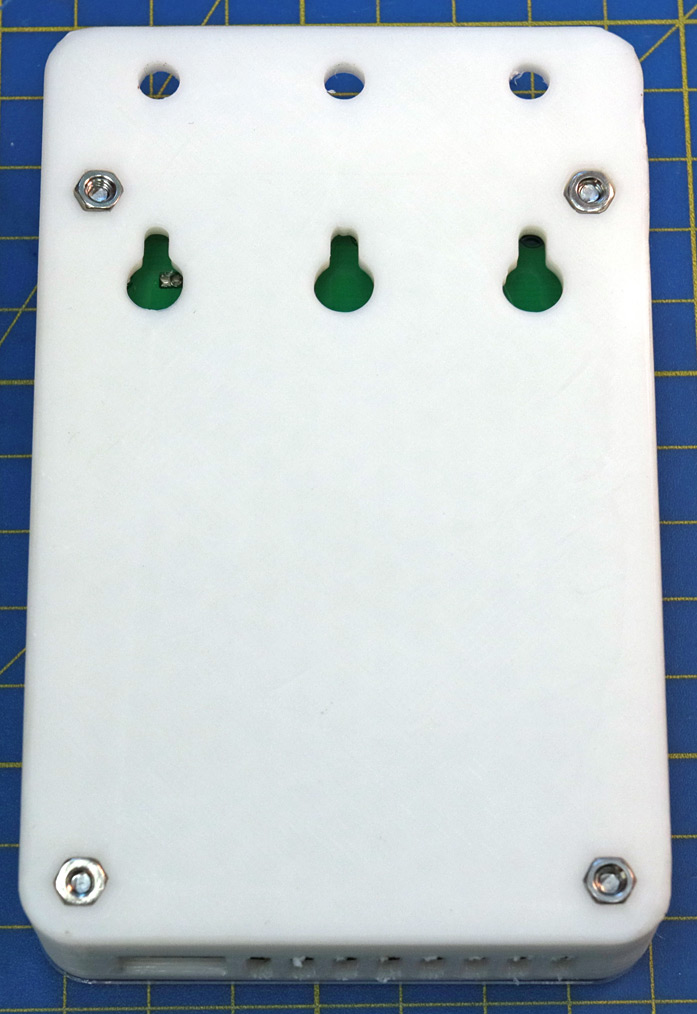
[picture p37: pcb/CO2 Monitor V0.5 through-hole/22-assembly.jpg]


12. Alternatively start with the case in the correct orientation and place the PCB into the case. You can insert the hex nuts first and secure them in place, or add them later, depending on what works best for you. Remove the protective film from the display. Slide the stand offs over a screw-driver or hex (Allen) key into position and carefully let them rest on the PCB before placing the front panel on top. The stand offs don't need to be perfectly aligned and the front panel can be moved sideways to some degree while inserting the screws through the panel and stand offs into the bottom holes of the case. Secure the screws with a hex (Allen) key without overtightening them.

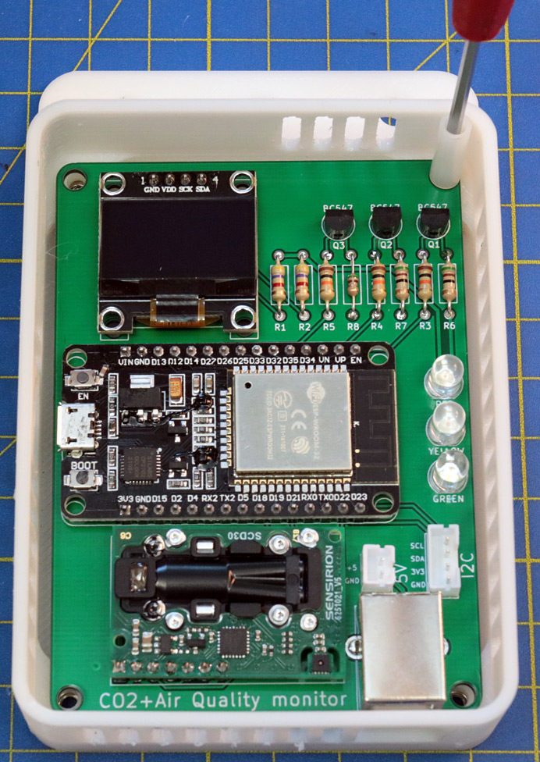
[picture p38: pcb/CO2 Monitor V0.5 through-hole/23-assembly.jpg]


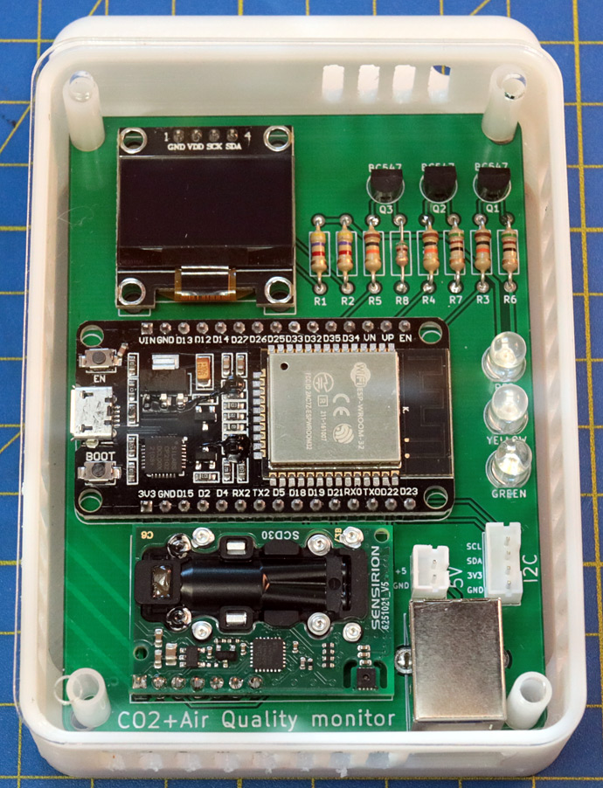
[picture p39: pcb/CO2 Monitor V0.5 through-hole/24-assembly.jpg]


13. Finally stick the small diffusor film over the LEDs to make them better visible and less blinding.

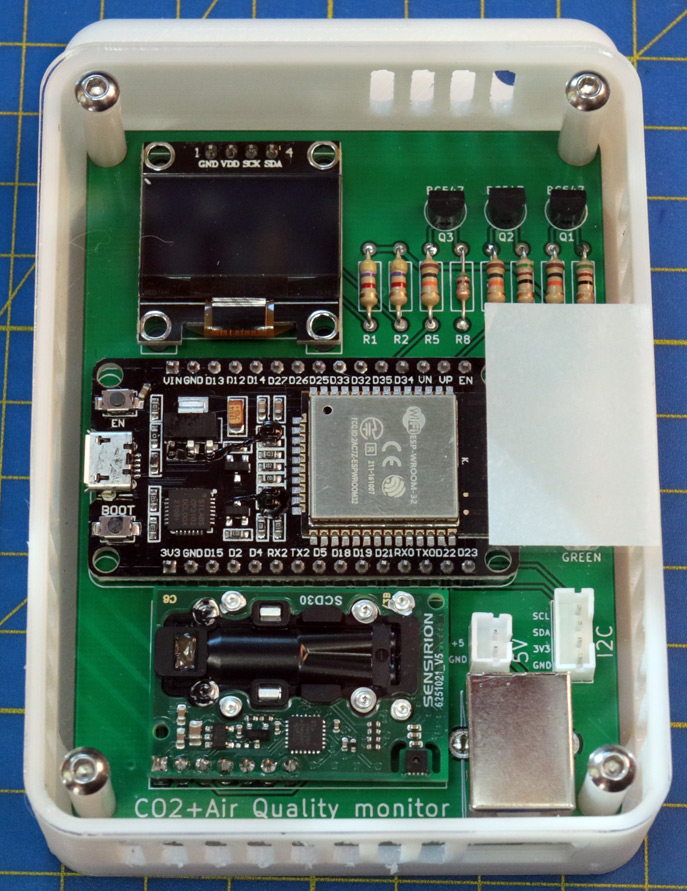
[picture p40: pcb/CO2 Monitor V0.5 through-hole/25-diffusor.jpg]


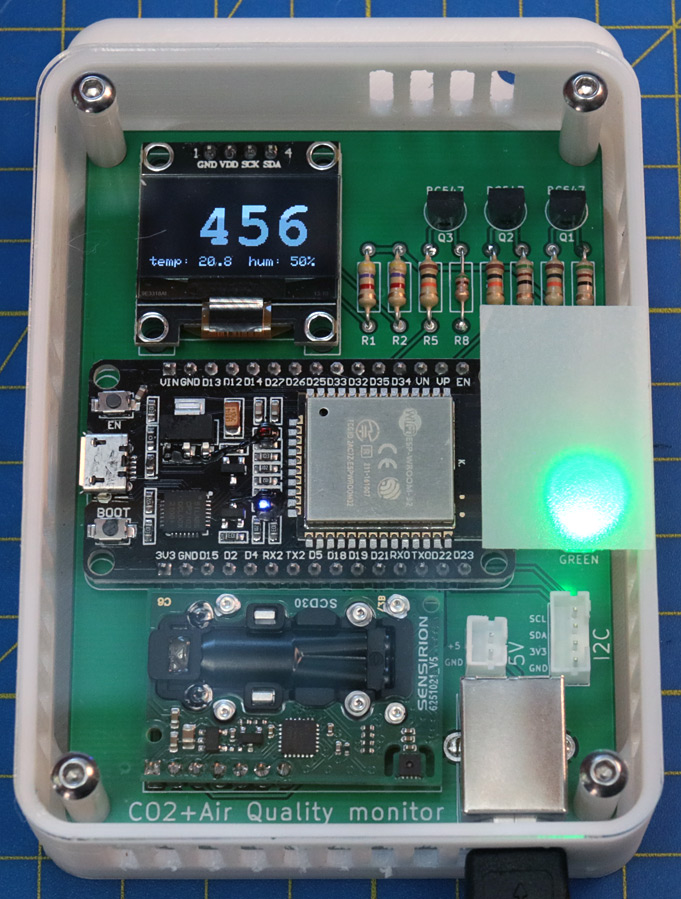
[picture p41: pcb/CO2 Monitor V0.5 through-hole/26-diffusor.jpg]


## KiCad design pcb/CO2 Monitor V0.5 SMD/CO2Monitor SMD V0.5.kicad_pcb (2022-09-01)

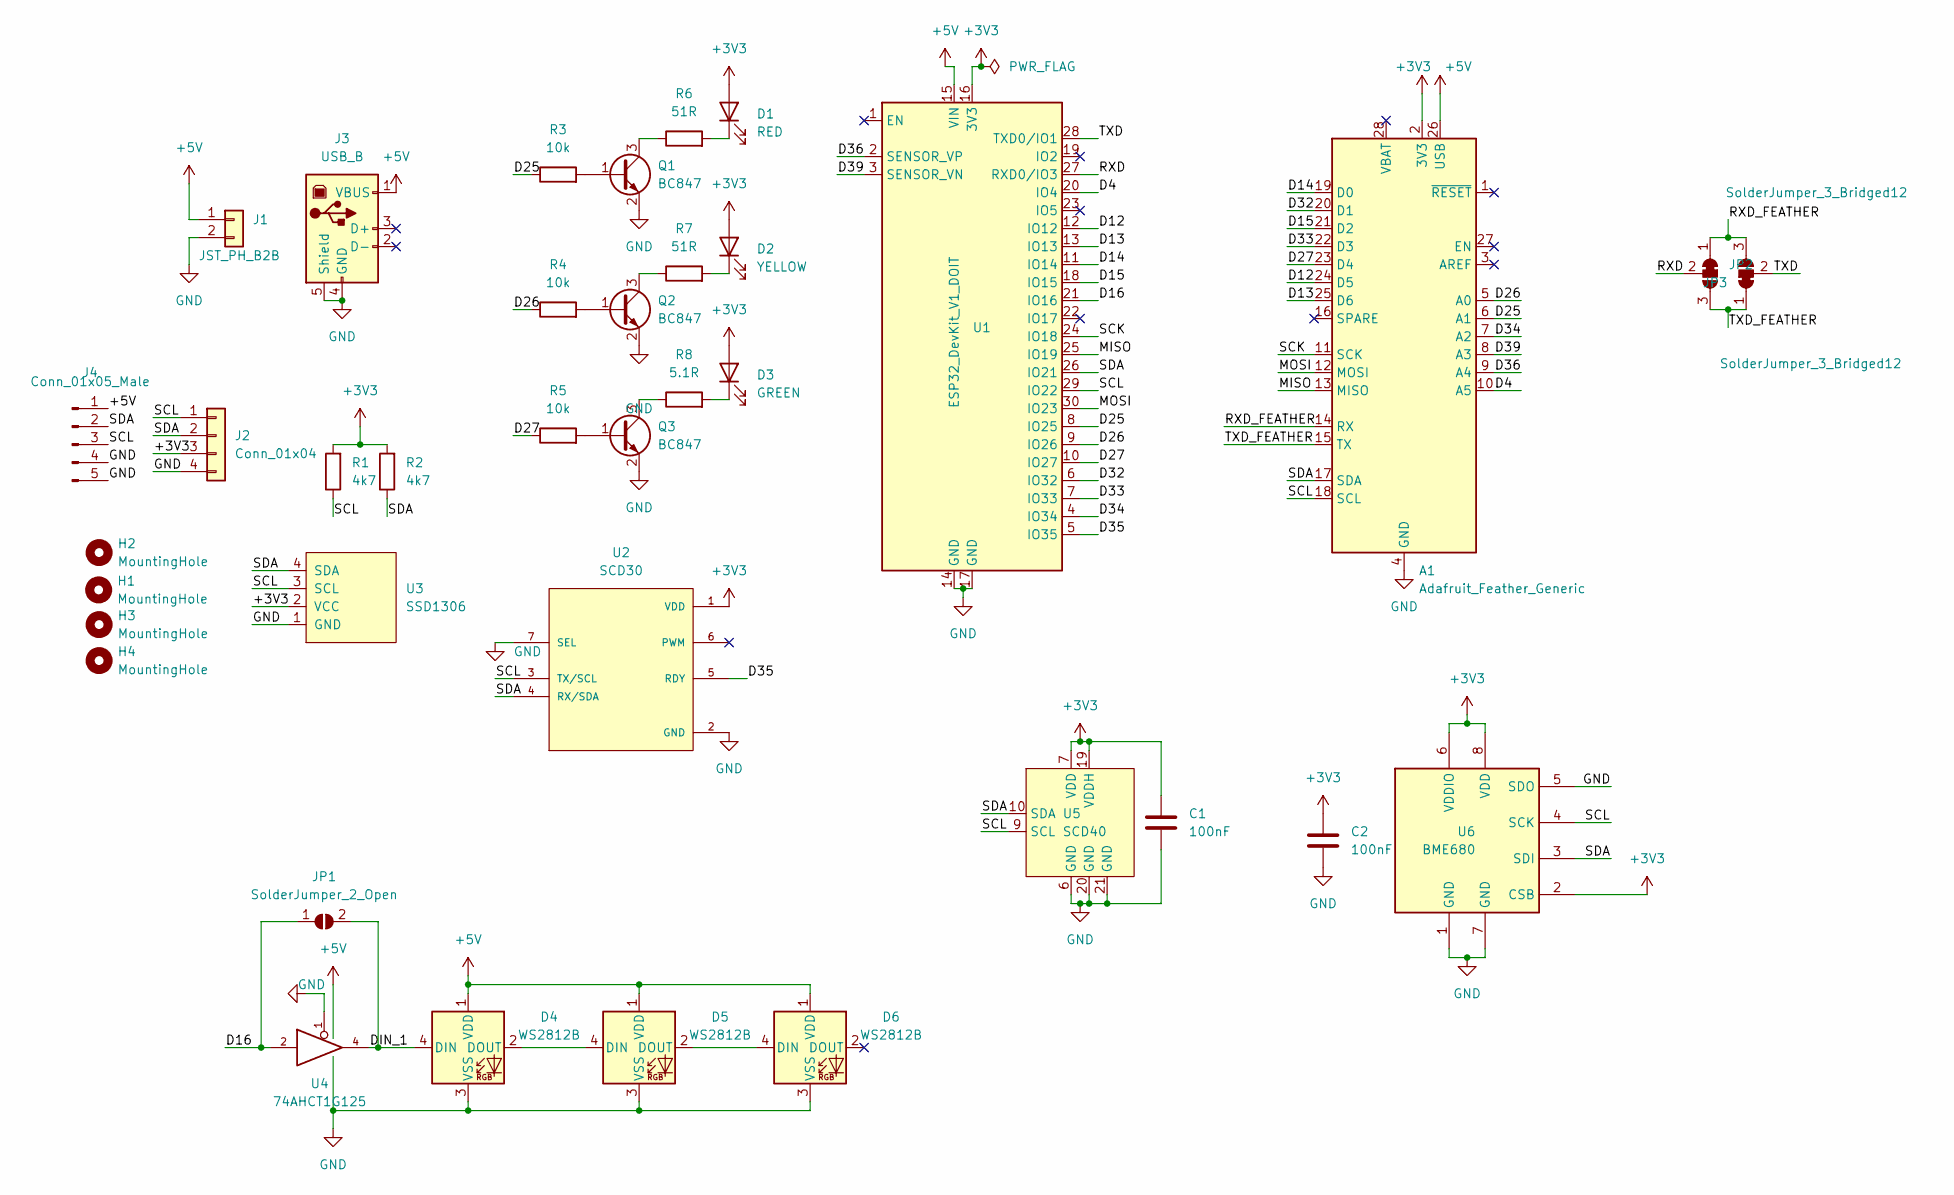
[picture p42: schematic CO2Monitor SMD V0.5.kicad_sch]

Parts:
A1: Adafruit_Feather_Generic; Adafruit_Feather
C1, C2: 100nF; C_0805_2012Metric
D1: RED; LED_D5.0mm_Clear
D2: YELLOW; LED_D5.0mm_Clear
D3: GREEN; LED_D5.0mm_Clear
D4, D5, D6: WS2812B; LED_WS2812B_PLCC4_5.0x5.0mm_P3.2mm
H1, H2, H3, H4: MountingHole; MountingHole_3.5mm
J1: JST_PH_B2B; JST_PH_B2B-PH-K_1x02_P2.00mm_Vertical
J2: Conn_01x04; JST_PH_B4B-PH-K_1x04_P2.00mm_Vertical
J3: USB_B; TE_1-1734346-1
J4: Conn_01x05_Male
JP1: SolderJumper_2_Open; SolderJumper-2_P1.3mm_Open_TrianglePad1.0x1.5mm
JP2, JP3: SolderJumper_3_Bridged12; SolderJumper-3_P1.3mm_Bridged12_RoundedPad1.0x1.5mm
Q1, Q2, Q3: BC847; SOT-23
R1, R2: 4k7; R_0805_2012Metric
R3, R4, R5: 10k; R_0805_2012Metric
R6, R7: 51R; R_0805_2012Metric
R8: 5.1R; R_0805_2012Metric
U1: ESP32_DevKit_V1_DOIT; esp32_devkit_v1_doit
U2: SCD30; PARTREV D1
U3: SSD1306; OLED_128x64_0.96_small_no_holes
U4: 74AHCT1G125; SOT-23-5
U5: SCD40; SCD40-D-R1
U6: BME680; Bosch_LGA-8_3x3mm_P0.8mm_ClockwisePinNumbering

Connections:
+3V3: A1.2 (3V3), C1.1, C2.1, D1.2 (A), D2.2 (A), D3.2 (A), J2.3, R1.2, R2.2, U1.16 (3V3), U2.1 (VDD), U3.2 (VCC), U5.7 (VDD), U5.19 (VDDH), U6.2 (CSB), U6.6 (VDDIO), U6.8 (VDD)
+5V: A1.26 (USB), D4.1 (VDD), D5.1 (VDD), D6.1 (VDD), J1.1, J3.1 (VBUS), J4.1, U1.15 (VIN), U4.5 (VCC)
/D4: A1.10 (A5), U1.20 (IO4)
/D12: A1.24 (D5), U1.12 (IO12)
/D13: A1.25 (D6), U1.13 (IO13)
/D14: A1.19 (D0), U1.11 (IO14)
/D15: A1.21 (D2), U1.18 (IO15)
/D16: JP1.1 (A), U1.21 (IO16), U4.2
/D25: A1.6 (A1), R3.1, U1.8 (IO25)
/D26: A1.5 (A0), R4.1, U1.9 (IO26)
/D27: A1.23 (D4), R5.1, U1.10 (IO27)
/D32: A1.20 (D1), U1.6 (IO32)
/D33: A1.22 (D3), U1.7 (IO33)
/D34: A1.7 (A2), U1.4 (IO34)
/D35: U1.5 (IO35), U2.5 (RDY)
/D36: A1.9 (A4), U1.2 (SENSOR_VP)
/D39: A1.8 (A3), U1.3 (SENSOR_VN)
/DIN_1: D4.4 (DIN), JP1.2 (B), U4.4
/MISO: A1.13 (MISO), U1.25 (IO19)
/MOSI: A1.12 (MOSI), U1.30 (IO23)
/RXD: JP2.2 (C), U1.27 (RXD0/IO3)
/RXD_FEATHER: A1.14 (RX), JP2.1 (A), JP3.3 (B)
/SCK: A1.11 (SCK), U1.24 (IO18)
/SCL: A1.18 (SCL), J2.1, J4.3, R1.1, U1.29 (IO22), U2.3 (TX/SCL), U3.3 (SCL), U5.9 (SCL), U6.4 (SCK)
/SDA: A1.17 (SDA), J2.2, J4.2, R2.1, U1.26 (IO21), U2.4 (RX/SDA), U3.4 (SDA), U5.10 (SDA), U6.3 (SDI)
/TXD: JP3.2 (C), U1.28 (TXD0/IO1)
/TXD_FEATHER: A1.15 (TX), JP2.3 (B), JP3.1 (A)
GND: A1.4 (GND), C1.2, C2.2, D4.3 (VSS), D5.3 (VSS), D6.3 (VSS), J1.2, J2.4, J3.4 (GND), J3.5 (Shield), J4.4, J4.5, Q1.2 (E), Q2.2 (E), Q3.2 (E), U1.14 (GND), U1.17 (GND), U2.2 (GND), U2.7 (SEL), U3.1 (GND), U4.1, U4.3 (GND), U5.6 (GND), U5.20 (GND), U5.21 (GND), U6.1 (GND), U6.5 (SDO), U6.7 (GND)
unnamed: D1.1 (K), R6.2
unnamed: D2.1 (K), R7.2
unnamed: D3.1 (K), R8.2
unnamed: D4.2 (DOUT), D5.4 (DIN)
unnamed: D5.2 (DOUT), D6.4 (DIN)
unnamed: Q1.1 (B), R3.2
unnamed: Q1.3 (C), R6.1
unnamed: Q2.1 (B), R4.2
unnamed: Q2.3 (C), R7.1
unnamed: Q3.1 (B), R5.2
unnamed: Q3.3 (C), R8.1

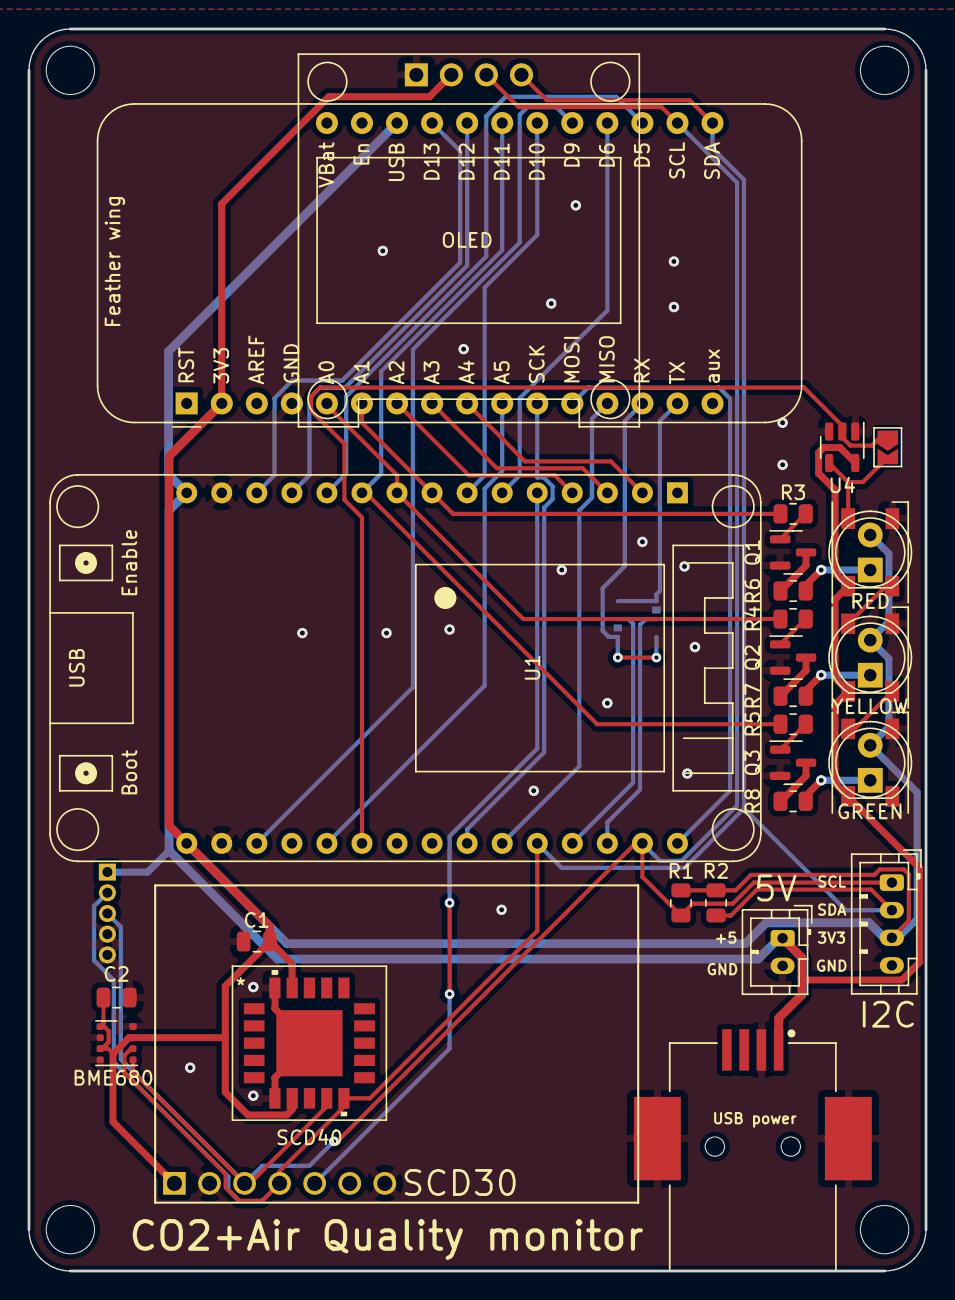
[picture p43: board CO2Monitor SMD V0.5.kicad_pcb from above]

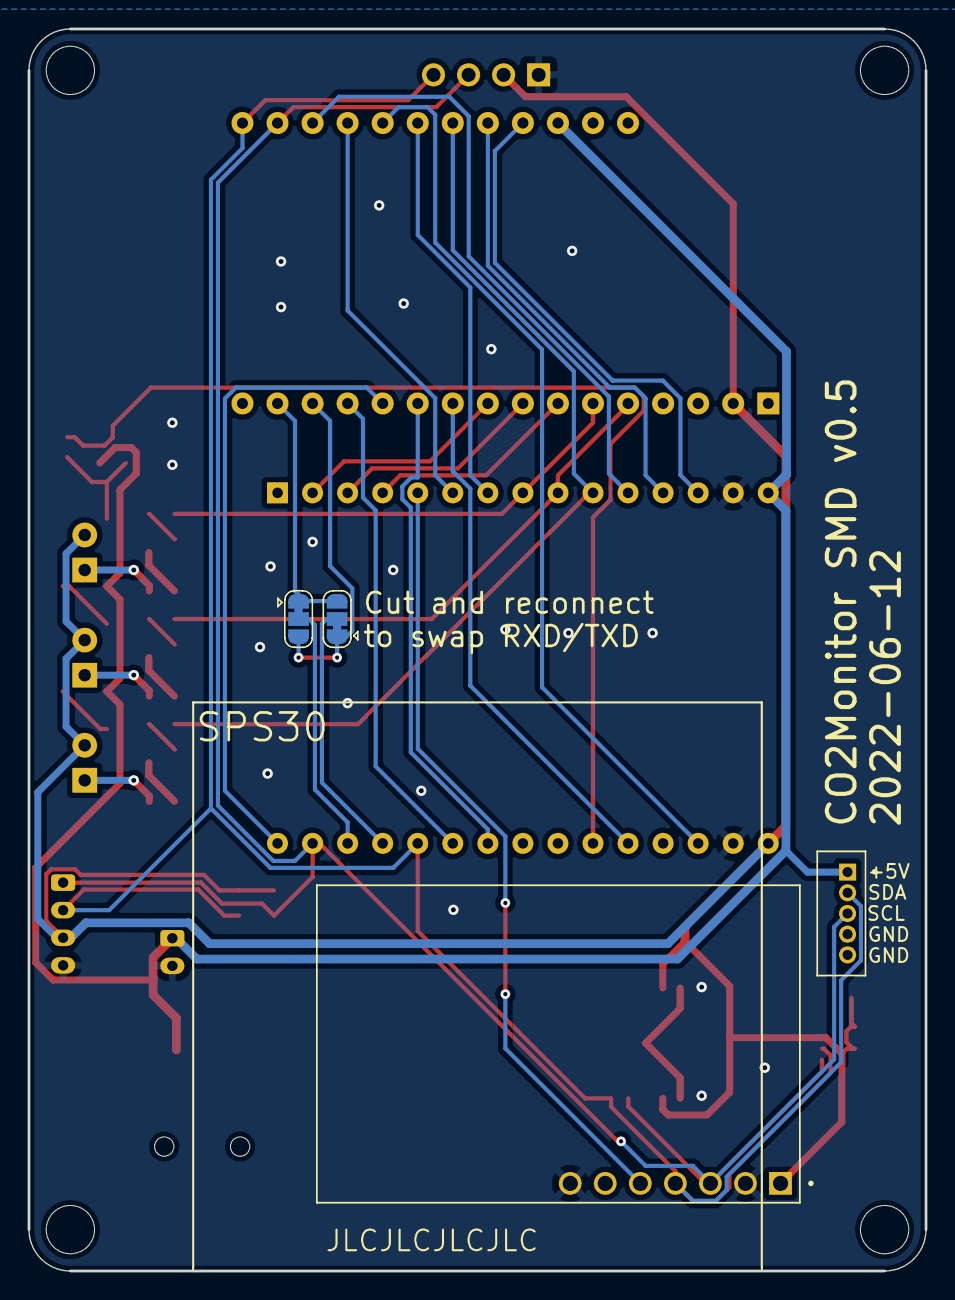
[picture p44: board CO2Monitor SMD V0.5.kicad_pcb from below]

Board: 2 copper layers, 65.0 x 90.0 mm, 37 parts (4 on the bottom side), 39 nets.

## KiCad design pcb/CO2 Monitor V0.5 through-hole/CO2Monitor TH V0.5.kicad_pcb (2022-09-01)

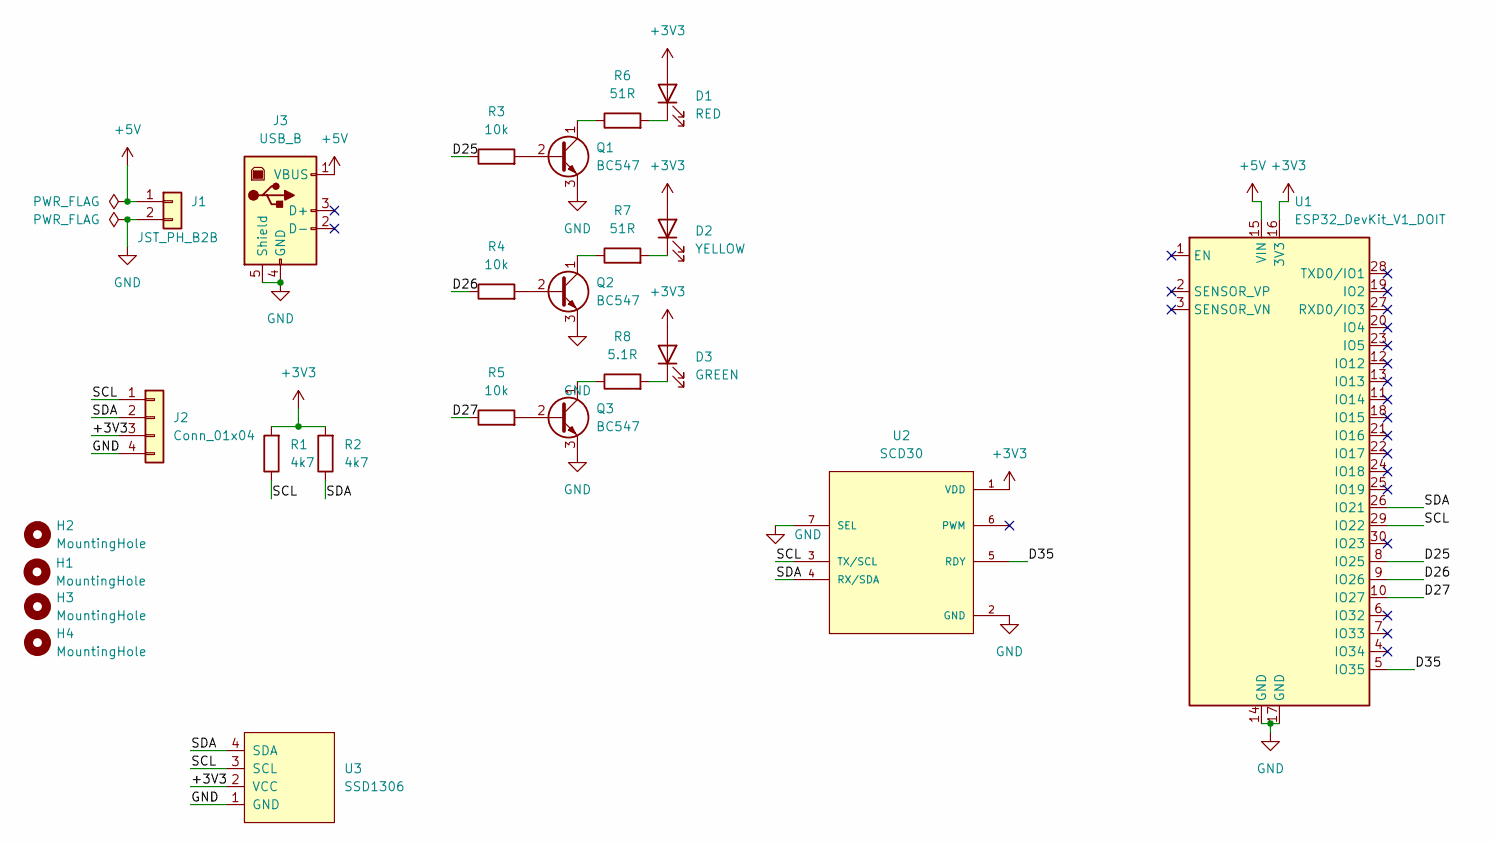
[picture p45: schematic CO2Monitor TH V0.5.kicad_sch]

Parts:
D1: RED; LED_D5.0mm_Clear
D2: YELLOW; LED_D5.0mm_Clear
D3: GREEN; LED_D5.0mm_Clear
H1, H2, H3, H4: MountingHole; MountingHole_3.5mm
J1: JST_PH_B2B; JST_PH_B2B-PH-K_1x02_P2.00mm_Vertical
J2: Conn_01x04; JST_PH_B4B-PH-K_1x04_P2.00mm_Vertical
J3: USB_B; USB_B_OST_USB-B1HSxx_Horizontal
Q1, Q2, Q3: BC547; TO-92_Inline
R1, R2: 4k7; R_Axial_DIN0207_L6.3mm_D2.5mm_P10.16mm_Horizontal
R3, R4, R5: 10k; R_Axial_DIN0207_L6.3mm_D2.5mm_P10.16mm_Horizontal
R6, R7: 51R; R_Axial_DIN0207_L6.3mm_D2.5mm_P10.16mm_Horizontal
R8: 5.1R; R_Axial_DIN0207_L6.3mm_D2.5mm_P10.16mm_Horizontal
U1: ESP32_DevKit_V1_DOIT; esp32_devkit_v1_doit
U2: SCD30; PARTREV D1
U3: SSD1306; OLED_128x64_0.96_small

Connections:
+3V3: D1.2 (A), D2.2 (A), D3.2 (A), J2.3, R1.2, R2.2, U1.16 (3V3), U2.1 (VDD), U3.2 (VCC)
+5V: J1.1, J3.1 (VBUS), U1.15 (VIN)
/D25: R3.1, U1.8 (IO25)
/D26: R4.1, U1.9 (IO26)
/D27: R5.1, U1.10 (IO27)
/D35: U1.5 (IO35), U2.5 (RDY)
/SCL: J2.1, R1.1, U1.29 (IO22), U2.3 (TX/SCL), U3.3 (SCL)
/SDA: J2.2, R2.1, U1.26 (IO21), U2.4 (RX/SDA), U3.4 (SDA)
GND: J1.2, J2.4, J3.4 (GND), J3.5 (Shield), Q1.3 (E), Q2.3 (E), Q3.3 (E), U1.14 (GND), U1.17 (GND), U2.2 (GND), U2.7 (SEL), U3.1 (GND)
unnamed: D1.1 (K), R6.2
unnamed: D2.1 (K), R7.2
unnamed: D3.1 (K), R8.2
unnamed: Q1.1 (C), R6.1
unnamed: Q1.2 (B), R3.2
unnamed: Q2.1 (C), R7.1
unnamed: Q2.2 (B), R4.2
unnamed: Q3.1 (C), R8.1
unnamed: Q3.2 (B), R5.2

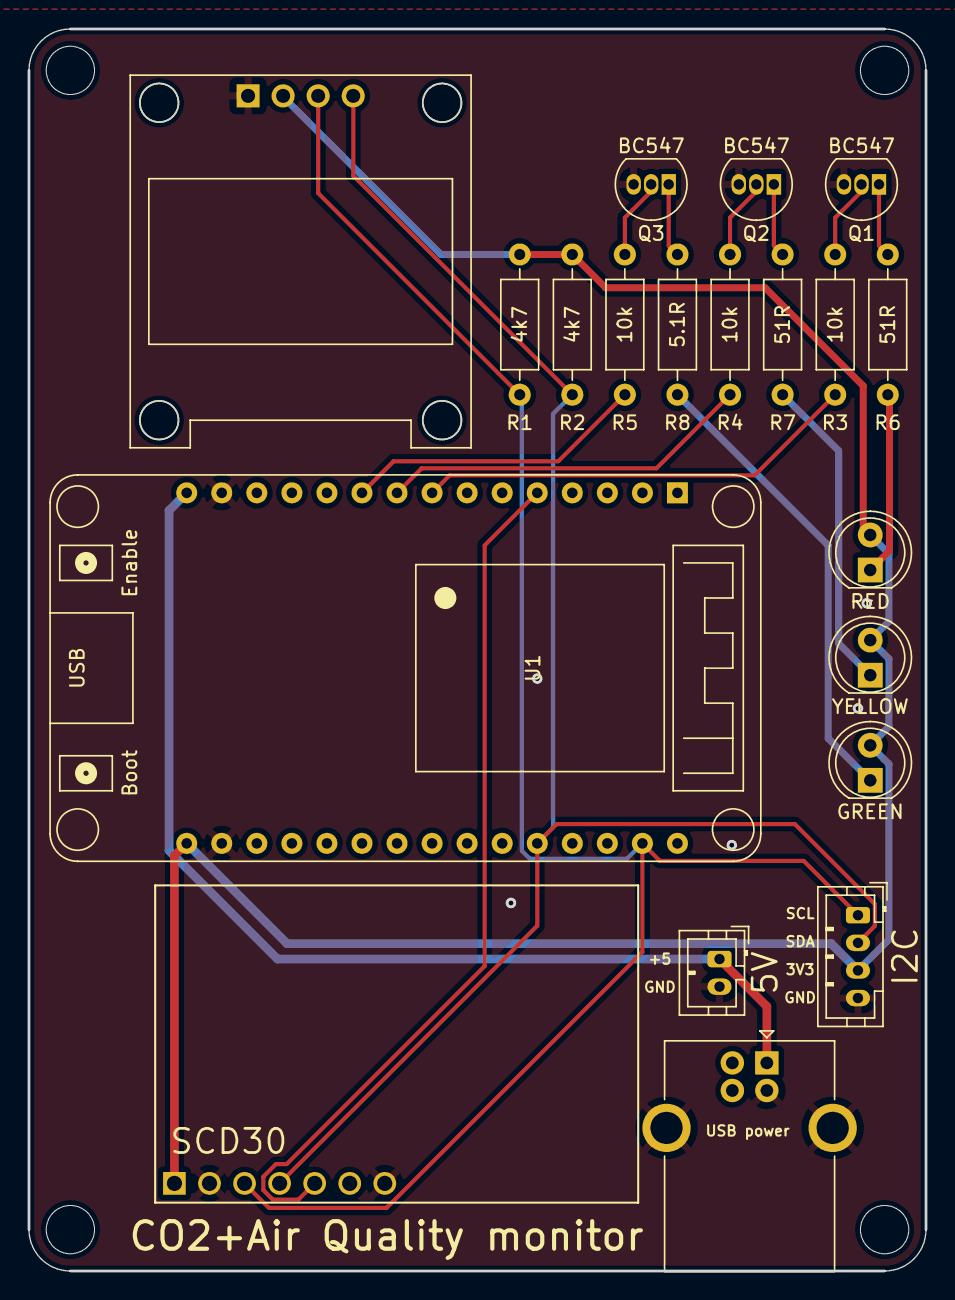
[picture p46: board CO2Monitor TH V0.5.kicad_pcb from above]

Board: 2 copper layers, 65.0 x 90.0 mm, 24 parts (1 on the bottom side), 18 nets.

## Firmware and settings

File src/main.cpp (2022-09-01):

#include <globals.h>
#include <Arduino.h>
#include <config.h>

#include <WiFi.h>
#include <Wire.h>
#include <i2c.h>
#include <esp_event.h>
#include <esp_err.h>

#include <configManager.h>
#include <mqtt.h>
#include <sensors.h>
#include <scd30.h>
#include <scd40.h>
#include <sps_30.h>
#include <housekeeping.h>
#include <lcd.h>
#include <trafficLight.h>
#include <neopixel.h>
#include <featherMatrix.h>
#include <hub75.h>
#include <bme680.h>
#include <wifiManager.h>
#include <ota.h>

// Local logging tag
static const char TAG[] = __FILE__;

Model* model;
LCD* lcd;
TrafficLight* trafficLight;
Neopixel* neopixel;
FeatherMatrix* featherMatrix;
HUB75* hub75;
SCD30* scd30;
SCD40* scd40;
SPS_30* sps30;
BME680* bme680;
TaskHandle_t sensorsTask;

bool hasLEDs = false;
bool hasNeoPixel = false;
bool hasFeatherMatrix = false;
bool hasHub75 = false;

const uint32_t debounceDelay = 50;
volatile uint32_t lastBtnDebounceTime = 0;
volatile uint8_t buttonState = 0;
uint8_t oldConfirmedButtonState = 0;
uint32_t lastConfirmedBtnPressedTime = 0;

void ICACHE_RAM_ATTR buttonHandler() {
  buttonState = (digitalRead(TRIGGER_PIN) ? 0 : 1);
  lastBtnDebounceTime = millis();
}

void stopHub75DMA() {
  if (hasHub75 && hub75) hub75->stopDMA();
}

void updateMessage(char const* msg) {
  if (lcd) {
    lcd->updateMessage(msg);
  }
}

void setPriorityMessage(char const* msg) {
  if (lcd) {
    lcd->setPriorityMessage(msg);
  }
}

void clearPriorityMessage() {
  if (lcd) {
    lcd->clearPriorityMessage();
  }
}

void modelUpdatedEvt(uint16_t mask, TrafficLightStatus oldStatus, TrafficLightStatus newStatus) {
  if (lcd) lcd->update(mask, oldStatus, newStatus);
  if (hasLEDs && trafficLight) trafficLight->update(mask, oldStatus, newStatus);
  if (hasNeoPixel && neopixel) neopixel->update(mask, oldStatus, newStatus);
  if (hasFeatherMatrix && featherMatrix) featherMatrix->update(mask, oldStatus, newStatus);
  if (hasHub75 && hub75) hub75->update(mask, oldStatus, newStatus);
  if ((mask & M_PRESSURE) && I2C::scd40Present() && scd40) scd40->setAmbientPressure(model->getPressure());
  if ((mask & M_PRESSURE) && I2C::scd30Present() && scd30) scd30->setAmbientPressure(model->getPressure());
  if ((mask & ~M_CONFIG_CHANGED) != M_NONE) mqtt::publishSensors(mask);
}

void calibrateCo2SensorCallback(uint16_t co2Reference) {
  ESP_LOGI(TAG, "Starting calibration");
  if (lcd) lcd->setPriorityMessage("Starting calibration");
  if (I2C::scd30Present() && scd30) scd30->calibrateScd30ToReference(co2Reference);
  if (I2C::scd40Present() && scd40) scd40->calibrateScd40ToReference(co2Reference);
  vTaskDelay(pdMS_TO_TICKS(200));
  if (lcd) lcd->clearPriorityMessage();
}

void setTemperatureOffsetCallback(float temperatureOffset) {
  if (I2C::scd30Present() && scd30) scd30->setTemperatureOffset(temperatureOffset);
  if (I2C::scd40Present() && scd40) scd40->setTemperatureOffset(temperatureOffset);
}

float getTemperatureOffsetCallback() {
  if (I2C::scd30Present() && scd30) return scd30->getTemperatureOffset();
  if (I2C::scd40Present() && scd40) return scd40->getTemperatureOffset();
  return NaN;
}

uint32_t getSPS30AutoCleanInterval() {
  if (I2C::sps30Present && sps30) return sps30->getAutoCleanInterval();
  return 0;
}

boolean setSPS30AutoCleanInterval(uint32_t intervalInSeconds) {
  if (I2C::sps30Present && sps30) return sps30->setAutoCleanInterval(intervalInSeconds);
  return false;
}

boolean cleanSPS30() {
  if (I2C::sps30Present && sps30) return sps30->clean();
  return false;
}

uint8_t getSPS30Status() {
  if (I2C::sps30Present && sps30) return sps30->getStatus();
  return false;
}

void logCoreInfo() {
  esp_chip_info_t chip_info;
  esp_chip_info(&chip_info);
  ESP_LOGI(TAG,
    "This is ESP32 chip with %d CPU cores, WiFi%s%s, silicon revision "
    "%d, %dMB %s Flash",
    chip_info.cores,
    (chip_info.features & CHIP_FEATURE_BT) ? "/BT" : "",
    (chip_info.features & CHIP_FEATURE_BLE) ? "/BLE" : "",
    chip_info.revision, spi_flash_get_chip_size() / (1024 * 1024),
    (chip_info.features & CHIP_FEATURE_EMB_FLASH) ? "embedded"
    : "external");
  ESP_LOGI(TAG, "Internal Total heap %d, internal Free Heap %d",
    ESP.getHeapSize(), ESP.getFreeHeap());
#ifdef BOARD_HAS_PSRAM
  ESP_LOGI(TAG, "SPIRam Total heap %d, SPIRam Free Heap %d",
    ESP.getPsramSize(), ESP.getFreePsram());
#endif
  ESP_LOGI(TAG, "ChipRevision %d, Cpu Freq %d, SDK Version %s",
    ESP.getChipRevision(), ESP.getCpuFreqMHz(), ESP.getSdkVersion());
  ESP_LOGI(TAG, "Flash Size %d, Flash Speed %d", ESP.getFlashChipSize(),
    ESP.getFlashChipSpeed());
}

void eventHandler(void* event_handler_arg, esp_event_base_t event_base, int32_t event_id, void* event_data) {
  if (event_base == IP_EVENT && event_id == IP_EVENT_STA_GOT_IP) {
    ESP_LOGD(TAG, "eventHandler IP_EVENT IP_EVENT_STA_GOT_IP");
  } else if (event_base == WIFI_EVENT) {
    switch (event_id) {
      case WIFI_EVENT_STA_CONNECTED:
        ESP_LOGD(TAG, "eventHandler WIFI_EVENT WIFI_EVENT_STA_CONNECTED");
        digitalWrite(LED_PIN, HIGH);
        break;
      case WIFI_EVENT_STA_DISCONNECTED:
        ESP_LOGD(TAG, "eventHandler WIFI_EVENT WIFI_EVENT_STA_DISCONNECTED");
        digitalWrite(LED_PIN, LOW);
        break;
      default:
        ESP_LOGD(TAG, "eventHandler WIFI_EVENT %u", event_id);
        break;
    }
  } else {
    ESP_LOGD(TAG, "eventHandler %s %u", event_base, event_id);
  }
}

void setup() {
  pinMode(LED_PIN, OUTPUT);
  digitalWrite(LED_PIN, LOW);
  pinMode(TRIGGER_PIN, INPUT_PULLUP);
  Serial.begin(115200);
  esp_log_level_set("*", ESP_LOG_VERBOSE);
  ESP_LOGI(TAG, "CO2 Monitor v%s. Built from %s @ %s", APP_VERSION, SRC_REVISION, BUILD_TIMESTAMP);

  model = new Model(modelUpdatedEvt);

  logCoreInfo();

  ESP_ERROR_CHECK(esp_event_loop_create_default());
  ESP_ERROR_CHECK(esp_event_handler_register(WIFI_EVENT, ESP_EVENT_ANY_ID, eventHandler, NULL));
  ESP_ERROR_CHECK(esp_event_handler_register(IP_EVENT, IP_EVENT_STA_GOT_IP, eventHandler, NULL));

  // try to connect with known settings
  WiFi.begin();

  setupConfigManager();
  if (!loadConfiguration(config)) {
    getDefaultConfiguration(config);
    saveConfiguration(config);
  }
  logConfiguration(config);

  hasLEDs = (config.greenLed != 0 && config.yellowLed != 0 && config.redLed != 0);
  hasNeoPixel = (config.neopixelData != 0 && config.neopixelNumber != 0);
  hasFeatherMatrix = (config.featherMatrixClock != 0 && config.featherMatrixData != 0);
  hasHub75 = (config.hub75B1 != 0 && config.hub75B2 != 0 && config.hub75ChA != 0 && config.hub75ChB != 0 && config.hub75ChC != 0 && config.hub75ChD != 0
    && config.hub75Clk != 0 && config.hub75G1 != 0 && config.hub75G2 != 0 && config.hub75Lat != 0 && config.hub75Oe != 0 && config.hub75R1 != 0 && config.hub75R2 != 0);

  Wire.begin((int)SDA, (int)SCL, (uint32_t)I2C_CLK);

  I2C::initI2C();

  if (I2C::scd30Present()) scd30 = new SCD30(&Wire, model, updateMessage);
  if (I2C::scd40Present()) scd40 = new SCD40(&Wire, model, updateMessage);
  if (I2C::sps30Present()) sps30 = new SPS_30(&Wire, model, updateMessage);
  if (I2C::bme680Present()) bme680 = new BME680(&Wire, model, updateMessage);
  if (I2C::lcdPresent()) lcd = new LCD(&Wire, model);

  if (hasLEDs) trafficLight = new TrafficLight(model, config.redLed, config.yellowLed, config.greenLed);
  if (hasNeoPixel) neopixel = new Neopixel(model, config.neopixelData, config.neopixelNumber);
  if (hasFeatherMatrix) featherMatrix = new FeatherMatrix(model, config.featherMatrixData, config.featherMatrixClock);
  if (hasHub75) hub75 = new HUB75(model);

  mqtt::setupMqtt(
    model,
    calibrateCo2SensorCallback,
    setTemperatureOffsetCallback,
    getTemperatureOffsetCallback,
    getSPS30AutoCleanInterval,
    setSPS30AutoCleanInterval,
    cleanSPS30,
    getSPS30Status);

  xTaskCreatePinnedToCore(mqtt::mqttLoop,  // task function
    "mqttLoop",         // name of task
    8192,               // stack size of task
    (void*)1,           // parameter of the task
    2,                  // priority of the task
    &mqtt::mqttTask,    // task handle
    0);                 // CPU core

  xTaskCreatePinnedToCore(OTA::otaLoop,  // task function
    "otaLoop",         // name of task
    8192,               // stack size of task
    (void*)1,           // parameter of the task
    2,                  // priority of the task
    &OTA::otaTask,      // task handle
    1);                 // CPU core

  Sensors::setupSensorsLoop(scd30, scd40, sps30, bme680);
  sensorsTask = Sensors::start(
    "sensorsLoop",      // name of task
    4096,               // stack size of task
    2,                  // priority of the task
    1);                 // CPU core

  housekeeping::cyclicTimer.attach(30, housekeeping::doHousekeeping);

  OTA::setupOta(stopHub75DMA);

  attachInterrupt(TRIGGER_PIN, buttonHandler, CHANGE);

  ESP_LOGI(TAG, "Setup done.");
#ifdef SHOW_DEBUG_MSGS
  if (I2C::lcdPresent()) {
    lcd->updateMessage("Setup done.");
  }
#endif
}

void loop() {
  if (buttonState != oldConfirmedButtonState && (millis() - lastBtnDebounceTime) > debounceDelay) {
    oldConfirmedButtonState = buttonState;
    if (oldConfirmedButtonState == 1) {
      lastConfirmedBtnPressedTime = millis();
    } else if (oldConfirmedButtonState == 0) {
      uint32_t btnPressTime = millis() - lastConfirmedBtnPressedTime;
      ESP_LOGD(TAG, "lastConfirmedBtnPressedTime - millis() %u", btnPressTime);
      if (btnPressTime < 2000) {
        digitalWrite(LED_PIN, LOW);
        stopHub75DMA();
        WifiManager::startConfigPortal(updateMessage, setPriorityMessage, clearPriorityMessage);
      } else if (btnPressTime > 5000) {
        calibrateCo2SensorCallback(420);
      }
    }
  }

  vTaskDelay(pdMS_TO_TICKS(50));
}

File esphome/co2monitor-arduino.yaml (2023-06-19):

esphome:
  name: co2monitor-arduino
  name_add_mac_suffix: true
  platformio_options:
    upload_speed: 921600
  on_boot:
    then:
      - output.turn_off: blue_led
      - light.control:
            id: leds
            state: on
            red: 1
            green: 0
            blue: 0
      - delay: 0.5s
      - light.control:
            id: leds
            state: on
            red: 1
            green: 0.7
            blue: 0
      - delay: 0.5s
      - light.control:
            id: leds
            state: on
            red: 0
            green: 1
            blue: 0
      - delay: 0.5s
      - light.control:
            id: leds
            state: off
      - globals.set:
          id: other_id
          value: '10'
      - lambda: |-
          char idS[64];
          sprintf(idS, "co2monitor-dev/%u", id(node_id));
          id(mqttclient).set_topic_prefix(idS);
          char topic[256];
          sprintf(topic, "%s/down/setNodeId", idS);
          id(mqttclient).subscribe(topic, [=](const std::string &topic, const std::string &payload) {
              ESP_LOGD("setNodeId", "Got new nodeID: %s", payload.c_str());
              int newId = atoi(payload.c_str());
              // What a palaver, first set the new value by calling the globals.set action manually,
              // which updates it in memory only
              globals::GlobalVarSetAction<globals::RestoringGlobalsComponent<int>> *setAction;
              setAction = new globals::GlobalVarSetAction<globals::RestoringGlobalsComponent<int>>(node_id);
              setAction->set_value(newId);
              setAction->play();
              // Then make the global variable (in memory) write itself to the NVS queue
              node_id->loop();
              // Then force NVS to save now (instead of waiting 1 minute)
              global_preferences->sync();
              // So we can hopefully reboot with the new ID.
              ESP_LOGD("setNodeId", "nodeID is now : %u. Rebooting to action.", id(node_id));
              if (newId == id(node_id)) {
                App.reboot();
              }
          });

globals:
  - id: node_id
    type: int
    restore_value: true
    initial_value: '45'
  - id: other_id
    type: int
    restore_value: true
    initial_value: '45'
esp32:
  board: esp32doit-devkit-v1
  framework:
    type: arduino


wifi:
  id: wifi2

esp32_improv:
  id: improvConf
  authorizer: boot
  status_indicator: blue_led

logger:
  level: DEBUG

web_server:
  port: 80

mqtt:
  id: mqttclient
  broker: mqtt-dev.co2mon.nz
  username: co2monitor
  password: co2monitor
  discovery: false
  log_topic:
    topic: esphome/logs
    level: WARN

switch:
  - platform: factory_reset
    name: Restart with Factory Default Settings
    id: reset
    internal: true

binary_sensor:
  - platform: gpio
    pin:
      number: GPIO0
      mode:
        input: true
      inverted: true
    name: Boot Button
    id: boot
    internal: true
    on_click:
      - min_length: 5s
        max_length: 20s
        then:
          - switch.turn_on: reset

output:
  - platform: gpio
    id: blue_led
    pin:
      number: GPIO2
      mode:
        output: true

i2c:
  scl: GPIO22
  sda: GPIO21
  frequency: 100kHz

sensor:
  - platform: scd4x
    update_interval: "15s"
    co2:
      name: "CO2"
      id: co2
      on_value:
        - if:
            condition:
              sensor.in_range:
                  id: co2
                  below: 800
            then:
              - light.control:
                  id: leds
                  state: on
                  red: 0
                  green: 1
                  blue: 0
        - if:
            condition:
              sensor.in_range:
                id: co2
                above: 800
                below: 1000
            then:
              - light.control:
                    id: leds
                    state: on
                    red: 1
                    green: 0.7
                    blue: 0
        - if:
            condition:
              sensor.in_range:
                id: co2
                above: 1000
            then:
              - light.control:
                    id: leds
                    state: on
                    red: 1
                    green: 0
                    blue: 0
    temperature:
      name: "Temperature"
      id: temperature
    humidity:
      name: "Humidity"
      id: humidity

light:
  - platform: neopixelbus
    variant: WS2811
    num_leds: 3
    pin: GPIO16
    name: "RGB strip"
    id: leds
    default_transition_length: 0s
    internal: true

font:
  - file: "fonts/Roboto-Regular.ttf"
    id: roboto
    size: 15
  - file: "fonts/Roboto-Regular.ttf"
    id: roboto30
    size: 30
  - file: "fonts/Roboto-Regular.ttf"
    id: roboto10
    size: 10
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

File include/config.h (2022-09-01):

#ifndef _CONFIG_H
#define _CONFIG_H

#define OTA_URL               "https://otahost/co2monitor/firmware.json"
#define OTA_APP               "co2monitor"
//#define OTA_POLL

#define TRIGGER_PIN           0
#define LED_PIN               2

#define SCD30_RDY_PIN         35

#define I2C_CLK 100000UL
#define SCD30_I2C_CLK 50000UL   // SCD30 recommendation of 50kHz

static const char* CONFIG_FILENAME = "/config.json";
static const char* MQTT_ROOT_CA_FILENAME = "/mqtt_root_ca.pem";
static const char* MQTT_CLIENT_CERT_FILENAME = "/mqtt_client_cert.pem";
static const char* MQTT_CLIENT_KEY_FILENAME = "/mqtt_client_key.pem";

#define PWM_CHANNEL_LEDS        0

#endif

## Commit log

2022-06-13 Enable access to version data from other scripts
    It can be useful to get access to the versions in other custom scripts, so make
    git-rev.py importable (dropping the -) and create another script
    (build-src-flags.py) that imports it to provide the current functionality.
2022-06-13 Allow configuration of the release branch name
    This can be useful to forked repositories which may not want to release from
    'main' (which should track upstream directly) and instead have a separate
    'release' branch containing their merged changes.
2022-06-13 co2mon.nz versioning customizations
    * Add a tag to differentiate releases in this fork from upstream
    * Release off the 'release' branch not 'main'
    * Don't put square brackets around branch names, as it creates
    filenames with special characters if you use versions in filenames.
2022-06-13 Add a custom target to build/push an OTA to a node
    Requires a working webserver and MQTT setup and needs additional config
    in extra.ini such as:
    [ota]
    host = hostname
    path = fs/path
    url = https://hostname/url/path
    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
2022-06-20 Add a revised case design with internal nut slots
    This is a revised version of the original case design that eliminates the nuts
    on the back of the device in favour of nuts contained within a slot within the
    case itself (inspired by a technique used on some Prusa printer parts).
    Also removes the micro-USB slot on the side.
    [Case v0.5_15mm_USB.STL]
2023-06-16 Tweaks for -S3 based boards.
    Need to tidy this up and get it working for both...
    [partitions.csv]
2023-06-19 Create ESP32/ESP32S3 configs with common base
2023-06-20 Basic first cut of improv on push only handling
    First experience with a 'proper' esphome component.
2023-06-20 make Co2Improv a BinarySensor for esp32_improv
    The idea is that the button press triggers Co2Improv to put things into
    improv mode (which will update display, etc too) and then it also acts
    as the authorizer for the esp_improv module to avoid having to ask the
    user to press the button again.
2023-06-20 Add co2display component to sync LCD/LEDs state
    particularly for handling improv, etc.
2023-06-22 Add SHT30 support for temp/humidity on -s3 model
    Requires also moving SCD40 config out of base to device specific files
    so we can send its temp/humidity outputs somewhere different in the -S3
    model.
2025-02-23 convert neopixel-idf to a proper component.
    The 'custom' component type it was using is deprecated.
    Not sure if the config handling/schema is correct here yet.
    [neopixel-idf.h]
2025-02-24 Support calibration.
